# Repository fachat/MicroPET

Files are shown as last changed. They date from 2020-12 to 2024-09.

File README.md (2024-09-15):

# uPET R2

# NOTE: the newer version is in the [cbm_micropet](https://github.com/fachat/cbm_micropet) repository!

This is a re-incarnation of the Commodore PET computer(s) from the later 1970s.

It is build on a Eurocard board and has only parts that can still be obtained new in 2021.
The current version is 2.0B.

Picture of a MicroPET

Here is the [Overview video](https://youtu.be/COlfqcaY7rI)

Some more videos on the build process can be found here [YT 8-bit times](https://youtube.com/playlist?list=PLi1dzy7kw1iybjcUccgjCV4fhNH4IPWSx)

## Features

The board is built with a number of features:

- Commodore 3032 / 4032 / 8032 / 8296 with options menu to select at boot
  - Boot-menu to select different PET versions to run (BASIC 1, 2, 4)
  - 40 col character display
  - 80 col character display
  - 8296 memory map emulation
  - IEEE488 interface (card edge and 24pin flat ribbon cable)
  - Tape connector (card edge)
  - PET graphics keyboard, or alternatively a C64 keyboard
- Improved system design:
  - 512k video RAM, plus 512k fast RAM, accessible using banks on the W65816 CPU
  - boot from an SPI Flash ROM
  - up to 12.5 MHz mode (via configuration register)
  - VGA b/w video output
  - Write protection for the PET ROMs once copied to RAM
  - lower 32k RAM mappable from all of the 512k fast RAM
- Improved Video output:
  - Hires graphics mode (using a configuration register)
  - modifyable character set
  - 40/80 column display switchable
  - 25/50 rows display switch
  - multiple video pages mappable to $8000 video mem address

## Overview

The system architecture is actually rather simple, as you can see in the following graphics.

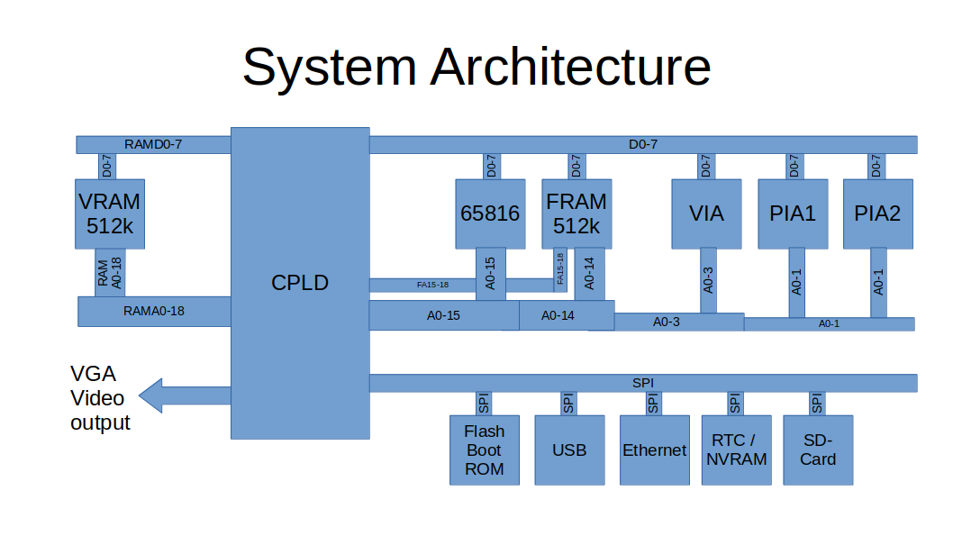
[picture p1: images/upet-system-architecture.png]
MicroPET System Architecture


The main functionality is "hidden" inside the CPLD. It does:

1. clock generation and management
2. memory mapping
3. video generation.
4. SPI interface and boot

On the CPU side of the CPLD it is actually a rather almost normal 65816 computer, 
with the exception that the bank register (that catches and stores the address lines 
A16-23 from the CPU's data bus) is in the CPLD, and that there is no ROM. The ROM has been
replaced with some code in the CPLD that copies the initial program to the CPU accessible
RAM, taking it from the Flash Boot ROM via SPI. This actually simplifies the design,
as 

1. parallel ROMs are getting harder to come by and
2. they are typically not as fast as is needed, and
3. with the SPI boot they don't occupy valuable CPU address space.

The video generation is done using time-sharing access to the video RAM.
The VGA output is 640x480 at 60Hz. So there is a 40ns slot per pixel on the screen, 
with a pixel clock of 25MHz.

The system runs at 12.5MHz, so a byte of pixel output (i.e. eight pixels) has four
memory accesses to VRAM. Two of them are reserved for video access, one for fetching the
character data (e.g. at $08xxx in the PET), and the second one to fetch the "character ROM"
data, i.e. the pixel data for a character. This is also stored in VRAM, and is being loaded
there from the Flash Boot ROM by the initial boot loader.

The CPLD reads the character data, stores it to fetch the character pixel data, and streams
that out using its internal video shift register.

For more detailled descriptions of the features and how to use them, pls see the subdirectory,
as described in the next section.

## Building

Here are four subdirectories:

- [Board](Board/) that contains the board schematics and layout
- [CPLD](CPLD/) contains the VHDL code to program the CPLD logic chip used, and describes the configuration options - including the [SPI](CPLD/SPI.md) usage
- [ROM](ROM/) ROM contents to boot
- [Case](Case/) 3-D printed supports and keyboards to mount board in a C64c case

### Board

To build the board, you have to find a provider that builds PCBs from Eagle .brd files.
Currently no gerbers are provided.

### CPLD

The CPLD is a Xilinx xc95288xl programmable logic chip. It runs on 3.3V, but is 5V tolerant,
so can be directly connected to 5V TTL chips. I programmed it in VHDL.

Unfortunately the W65xx parts are "only" CMOS, and not TTL input chips - but 3.3V is still above
the VCC/2 for the 5V chips. Only Phi2 needs improvements on the signal quality using a pull-up resistor
and specific VHDL programming.

### ROM

The ROM image can be built using gcc, xa65, and make. Use your favourite EPROM programmer to burn it into the SPI Flash chip.

The ROM contains images of all required ROM images for BASIC 1, 2, and 4, and corresponding editor ROMs, including
some that have been extended with wedges.

The updated editor ROMs are from [Steve's Editor ROM project](http://www.6502.org/users/sjgray/projects/editrom/index.html) and can handle C64 keyboards, has a DOS wedge included, and resets into the Micro-PET boot menu.
For more details see the [ROM description](ROM/README.md)

## Future Plans

These are future expansions I want to look into. Not all may be possible to implement.

- n/a

## Gallery

Picture of a MicroPET

Note: the published schematics and board has the extra wires fixed/included.

MicroPET with self-printed key caps

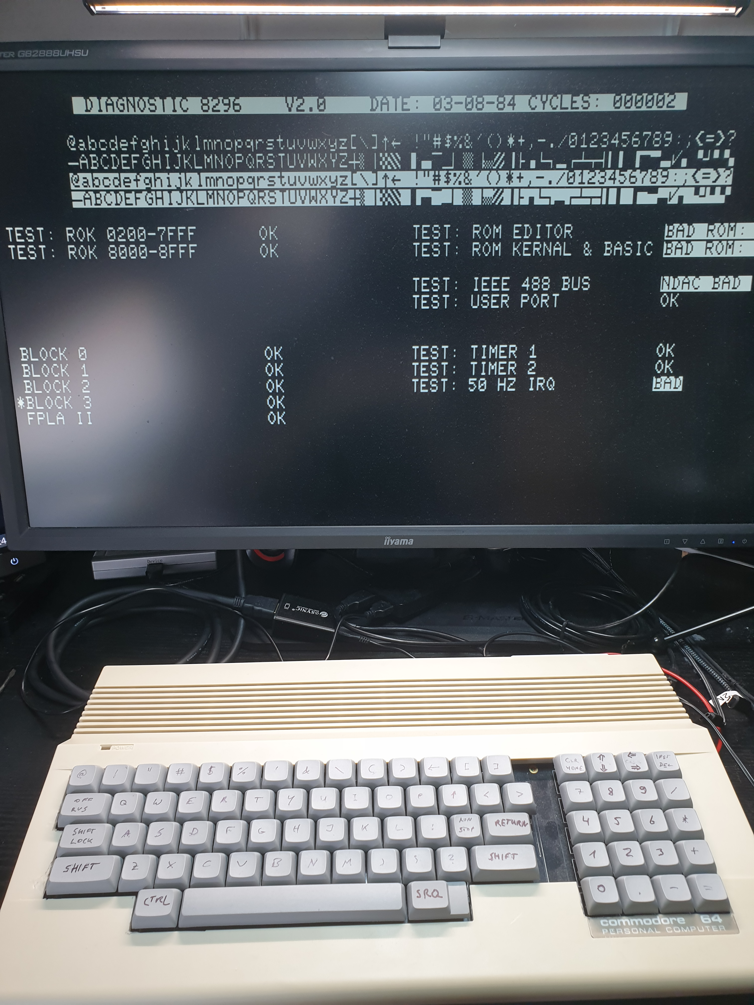
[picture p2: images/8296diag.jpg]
MicroPET running the 8296 burnin


MicroPET before adjusting a C64 case

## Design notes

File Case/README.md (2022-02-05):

# Installing the Micro-PET into a C64c case

I installed the Micro-PET into a C64c case, i.e. the flat one. The reason to select this type of case
is that there are new cases available since the original casts have been recovered.

## Board mounts

The board is screwed onto a support that is itself screwed to the bottom of the case.
Only one screw is used to directly screw the board to the case, the other screws fix the board to the support.

The back cover covers the case holes for the old expansion board hole that is not needed anymore.
It can also be used as template where to cut holes into the C64c case for the IEEE488, VGA, Ethernet and USB connectors.

[board support](board/MicroPET board mounts with batt holder.stl)
[back cover](board/Final MicroPET Back Cover.stl)

## Keyboard

### Options

There are three keyboard options available:

1. The open source [keyboard by Steve J. Gray](http://www.6502.org/users/sjgray/projects/mxkeyboards/index.html), using the "N-V1-R2" boards there.
2. The Petskey v1.0 keyboard from [texELEC](https://texelec.com/product/petskey/)
3. An original C64 keyboard.

The first two options are replacements for an N-type PET keyboard, the third options is a C64 keyboard.
The boot menu will detect which keyboard is used by noting which key is pressed to select the PET model, 
and will automatically load the right editor ROM (except for BASIC2 that only works with the N keyboard).

Note that options 1. and 2. will need MX key switches, preferrably of the 5 pin type that better locks in
and alignes in the right direction. Also, for thos switches you need to have appropriate key caps (see below).

### Supports

For each of the options there are different keyboard supports. You need the common
[keyboard support plate](kbd_support/C64c%20keyboard%20support%20plate.stl) and the C64 keyboard supports, i.e. two of [supports for C64 keyboards](kbd_support/C64%20keyboard%20support.stl).
Using these parts you can use a C64 keyboard. 

If you want to use a PET keyboard, you have two options:
1. two [supports for SJG keyboards](kbd_support/sjg%20keybd%20full%20support%20plate.stl) or
2. two [supports for petskey keyboards](kbd_support/petskey%20full%20support%20plate.stl), or

Two of each of those make up a keyboard base plate, where you only need to clip in the PCB for the keyboard
with the mounted key switches. Then they have about the same dimensions as a C64 keyboard, and you can use
them on top of the C64 keyboard support stands.

### Standard Keycaps

As, for the self-built keyboards from option 1 or 2 some standard MX switches are used, standard 
key caps can be used as well. There is one caveat, however.

Newer key caps typically have a different inclination for each row of keys, that is the angle of the top key surface against the horizontal
is different for each row. This is to facilitate easier typing. In fact even the C64 keyboard has this.
The old PET keyboards, however, have the same angle - which is not zero! - for all rows. This makes it easier to use the same cap (in terms of physical dimensions)
on all rows, and just print on a different character for each key. Read more on those [key profiles](https://switchandclick.com/sa-vs-dsa-vs-oem-vs-cherry-vs-xda-keycap-profiles/).

I used two type of standard key caps:

1. [XDA profile, unmarked](https://www.amazon.de/gp/product/B06XSHK528/): this set of key caps does not have a print on it, and all keys have the same angle - zero. So it is 
possible to use any of the key caps in any row. Which is important, as you need a specific number of keys for each key width.
Also, this set has space bars in different lengths, and there is one that fits the 6.25 character wide space bar for the petskey and sjg keyboards.
For the markings I just used a pen...

2. This one [Glorious PC Gaming Race ABS Doubleshot black, ANSI layout GAKC-045](https://www.caseking.de/glorious-pc-gaming-race-abs-doubleshot-schwarz-ansi-us-layout-gakc-045.html) I actually bought more or less 
by accident. I only noticed that it has different angles per row when I tried it out. However, with the amount of caps I was able to only
use a wrong angle on Shift Lock, left Shift, Return and "4" - but it's barely noticable.
For the markings I used template from Steve's page, printed it on sticky paper, cut it out and glued it on the keys where the original did not fit.

### Printed Keycaps

As a third option I used 3-D printed key caps that I designed myself. 

The keycaps are made of three parts each:
1) a key form created by a parametric generator,
2) the top character print, extruded from the key form,
3) the front character (mostly the shifted character), extruded from the key form.

I created all parts, and integrated them in the [Tinkercad](https://tinkercad.com) web tool.

The key form is created using OpenSCAD by a [parametric generator](https://www.thingiverse.com/thing:2783650) (by Thingieverse user rsheldiii, published under the [CC BY-SA 3.0](https://creativecommons.org/licenses/by-sa/3.0/) license). Here is the [parameter file](keycaps/key_cbm3_customizer.scad). Only the key width needs to be adapted, and the inversion of the top for the space key.

Most of the top character prints are made from a [Microgramm font](https://www.wfonts.com/font/microgramma), converted to SVG using the [Font Squirrel](https://www.fontsquirrel.com/tools/webfont-generator) web page.

Some top characters, and especially the top words ("SHIFT", "RUN STOP" etc) are taken from [Steve's github page](https://github.com/sjgray/CBM-MX-Keyboards/tree/master/stickers). As SVG exported from inkscape did not work when imported
into tinkercad, I had to make screenshots from each character, and convert these screenshots into SVGs using this [online converter](https://image.online-convert.com/convert-to-svg). 

The front characters are all from an [SVG file from wikipedia](https://en.wikipedia.org/wiki/Commodore_PET#/media/File:PET_Keyboard_improved.svg), from which I also took screenshots and converted to SVG as above.

You can find the STL files [here](keycaps/), in four parts due to its size.
Please note that it took me about 100+ hours just to print the full set of keys on my Snapmaker printer in high quality.
After printing you have to remove the supports that anchor the stem to the outside of the keycaps so it does
not break away when printing.

## Designs

Here are the links to the Tinkercad designs I created:

1. [Keycaps]( https://www.tinkercad.com/things/dNZ8wI2zuYY )
2. [base plate for keyboard support]( https://www.tinkercad.com/things/4DlYD3iQAby )
3. [keyboard plates for Steve Gray's keyboard (needed 2x, on top of C64 keyboard supports)](  https://www.tinkercad.com/things/a3phGKtNsUp  )
4. [keyboard plates for petskey keyboard (needed 2x, on top of C64 keyboard supports)](  https://www.tinkercad.com/things/5lenSoehSRu  )
5. [keyboard supports for C64 keyboard]( https://www.tinkercad.com/things/6t9EtqgGbSE )
6. [Board mount]( https://www.tinkercad.com/things/aFCF30m60Vp )
7. [Back cover]( https://www.tinkercad.com/things/5eZ8UNyYb2q )

## License

The material here is published under the Creative Commons Attribution-ShareAlike 3.0 [CC BY-SA 3.0](https://creativecommons.org/licenses/by-sa/3.0/) license.

## Gallery

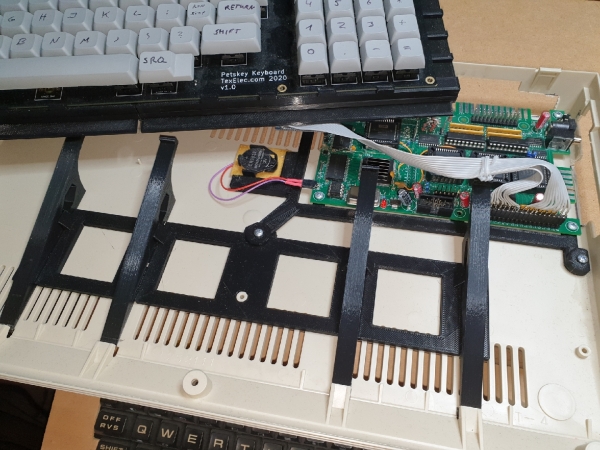
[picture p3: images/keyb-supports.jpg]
Keyboard supports


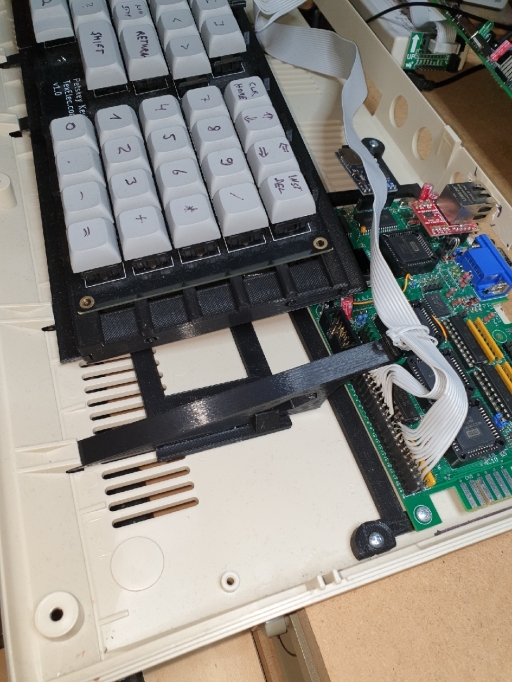
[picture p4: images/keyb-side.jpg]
Keyboard side view with plate


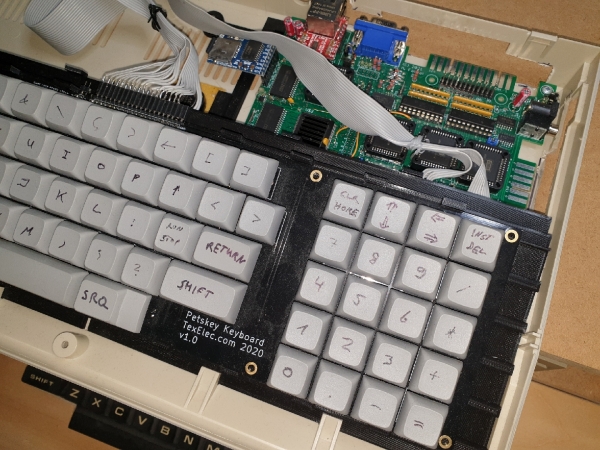
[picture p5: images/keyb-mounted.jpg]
Keyboard mounted on plate


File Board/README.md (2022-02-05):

# Board V2.1A

The board is a two-layer Eurocard, i.e. 160mm x 100mm.

## Schematics & Layout

The schematics and layout have been created with Cadsoft Eagle.
So, here you can find the 

- [micropet_v2.sch](micropet_v2.sch) and
- [micropet_v2.brd](micropet_v2.brd) files

But, you can still have a look at the schematics and layout using the
PNG images created

- [micropet_v2-sch-1.png](micropet_v2-sch-1.png) Part 1 - PETIO
- [micropet_v2-sch-2.png](micropet_v2-sch-2.png) Part 2 - CPLD, CPU, RAM
- [micropet_v2-sch-3.png](micropet_v2-sch-3.png) Part 3 - Power
- [micropet_v2-sch-4.png](micropet_v2-sch-4.png) Part 4 - Video and Audio output
- [micropet_v2-sch-5.png](micropet_v2-sch-5.png) Part 5 - SPI devices (Eth, USB, RTCC, ...)

## Bill of Material

The main chips are:

- 1x W65816S CPU
- 2x W65C21N PIA
- 1x W65C22N VIA

- 1x xc95288xl CPLD
- 2x 8x512k parallel SRAM with 25ns access time
- 2x 74LS641-1
- 1x 74LS145 4-to-10 BCD O.C. driver (keyboard)
- 1x 74LS07
- 1x DS1813 RESET controller

- 50 MHZ crystal oscillator

- Voltage regulator

- x 0.1uF bypass caps

- 5.1kOhm / 2.4kOhm pairs of resistor arrays for IEEE488
- 10kOhm pullup
- 1x 1kOhm pullup
- 1x 8x10kOhm resistor array (keyboard pull up)

- div. resistors/caps to generate 3.3V output

More details can be found in the [Eagle parts list](micropet_v2.parts).

## Changelog

### V2.1A

In this version I incorporated the fixes I had to apply to the first prototype board. Also, I changed the IEEE488 circuit such that it can now really work as a disk drive for another PET. This brings it in line with the CSA PETIO 1.2A/1.3A boards that have this functionaly fixed.

## Erratum

This section describes fixes from my 2.0A prototype board, and these are the cuts/additional wires you see on the pictures, where I fixed my 2.0A boards.

### 2.0C

- I pulled up /IRQ to 5V, but that was potentially backfeeding to the 3.3V SPI devices. A pull-up to 3.3V still worked just fine without problems

### 2.0B

- In 2.0A I planned to use the 74245 to drive the system's Phi2 clocks (CPU & I/O), and to level-shift it. But it turned out that this was not stable, so I reverted to the pull-up resistor method again
- I was missing a cross-sheet connection for the I/O Phi2 clock
- Also I was missing the SPI select line for the RTCC

- 
-

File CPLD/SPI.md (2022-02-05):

# SPI interface

## Overview

The SPI interface is as simple as I could make it, to save resources in the CPLD.

Nevertheless it has a transmit data register where data can be loaded to transmit, even if the
previous transmit is already in progress.
Also, there are two registers to read the data - one that just returns the current shift register value,
and another that automatically triggers reading a new byte from SPI.
These two features are implemented to increase throughput.

The CPHA and CPOL bits in the control register can be used to select the required SPI mode.

## Register Set

The SPI interface has four addresses, of which 3 are currently used:

- $e808: control register (read/write)
  - Bit 0-2: SPI device selection (write only)
  - Bit 3: - unused, must be 0
  - Bit 4: CPHA (write only)
  - Bit 5: CPOL (write only)
  - Bit 6: 1: tx data register is occupied; 0: tx data register is free, you can reload it (read only)
  - Bit 7: 1: shift register is in use (read only)

- $e809: data register (read/write)
  - Read: Bit 0-7: read the current state of the shift register, and trigger reading a new byte from SPI
  - Write: Bit 0-7: write to the transmit data register, and start shifting it out (waiting for a previous byte to finish if needed)

- $e80a: data register (peek)
  - Read: Bit 0-7: read the current state of the shift register

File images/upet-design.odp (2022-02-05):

## System Architecture

A0-14

A0-3

A0-1

A0-1

FA15-18

A0-15

D0-7

D0-7

D0-7

D0-7

D0-7

RAM
A0-18

D0-7

SPI

SPI

SPI

SPI

SPI

D0-7

RAMD0-7

CPLD

VRAM

512k

65816

FRAM

512k

VIA

PIA1

PIA2

FA15-18

A0-15

RAMA0-18

A0-14

A0-3

A0-1

VGA

Video

output

SPI

Flash
Boot
ROM

USB

Ethernet

RTC /
NVRAM

SD-
Card

## Memory Map (boot)

ipl

ipl

CPU address space (lower 1M)

64k
bank0

Banks 0 … 7

Banks 8 … 15

64k
bank0

64k 8296

Ext. bank

Banks 2 … 7

64k video
bank

Banks 9 … 15

512k FRAM

Physical address space

The CPLD can only write (the IPL code from Flash) to VRAM, so the initial

Mapping maps VRAM to banks 0-7 of the CPU

512k VRAM

## Memory Map

CPU address space (lower 1M)

0-32k

32-
64k

Banks 1 … 15

Any of 16

32k blocks

In FRAM

4k
V

Bank 0, or

8296 mem expansion

In bank 1

Any of four 2k positions in video bank

8k
Chr

rom

8k
Chr

64k
bank0

64k 8296

Ext. bank

Banks 2 … 7

64k video
bank

Banks 9 … 15

512k FRAM

Physical address space

512k VRAM

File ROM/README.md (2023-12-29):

# ROM contents

This folder contains files and code to build a ROM image that can be burned into the 512k ROM on the board, so that it actually boots.

- iplldr.a65: initial program loader, boots the machine by:
-- copying over character ROM image from start of ROM ($0f0000) to start of bank 7 (in RAM)
-- letting the user select which machine to boot (BASIC 2, BASIC 4/40 columns, BASIC 4/80 columns)
-- copying over selected PET ROM image to bank 0 ($a000-$ffff) ...
-- and executes a JMP through the RESET vector

For this work the ROM needs to contain:
- boot code
- character ROM
- system ROMs

## SPI FLash Memory Map

The IPL triggered by the CPLD loads the first 256 byte from the SPI flash. Following that is the
rest of the boot code as loaded by the initial IPL loader.
Then follow the various ROM images.

	Boot Image
        
        +----+ $1ffff
        |    |         SD-Card DOS code
        |    |         (16k)
        |    |
        +----+ $1c000
        |    |         USB driver code
        |    |         (8k)
        +----+ $1a000
        |    |         BASIC 1 alternate charrom 
        |    |         (as 16 byte/char)
        +----+ $18000
        |    |         8x BASIC 4 EDITOR
         ...           ROM images ($e000-$efff)
        |    |         Extended/orig, 40/80 columns, N-type/C64 kbd
        |    |
        +----+ $10000
        |    |         BASIC 4 Kernal ROM image
        +----+ $0F000
        |    |         BASIC 4 
        |    |         ROM image ($b000-$dfff)
        |    |         
        +----+ $0c000
        |    |         BASIC 2 
        |    |         ROM image ($c000-$ffff)
        |    |  
        |    |       
        +----+ $08000
        |    |         BASIC 1 
        |    |         ROM image ($c000-$ffff)
        |    |
        |    |
        +----+ $04000
        |    |         8k PET charrom
        |    |         (16 byte per character)
        +----+ $02000
        |    |         4k @MON in the PET4 variant (without editor extension)
        +----+ $01000
        |    |         Boot loader, first 256 byte IPL's by CPLD
        +----+ $00000

## Build

To build the ROM, just run "make".
This build process for bootimg downloads the necessary ROM images and sub-repos from the internet, builds the boot loader, and combines everything into a single boot image.
Then burn the resulting file "spiimg" into the lowest bank of the SPI Flash ROM (Address 0)

## Files

The following files are test files, or to build the ROMs:

- char8to16.c: converts a character ROM with 8 pixel rows per character to a 16 row per character image
- charPet2Invers.c: a PET charrom is only 2k and lacks inverted characters, as they are generated by hardware. This small program creates, from the 2k PET image, a full 4k image that contains the inverted characeters
- edit....asm: control files for Steve Gray's editor ROM project, to build the custom editor ROMs
-- edit40gx: 40 column for graphics keyboard with wedge and special keys
-- edit80gx: 80 column for graphics keyboard with wedge and special keys
-- edit40gxc: 40 column for C64 keyboard with wedge and special keys
-- edit80gxc: 80 column for C64 keyboard with wedge and special keys
-- edit40gc: 40 column for C64 keyboard (no further extensions) 
-- edit80gc: 80 column for C64 keyboard (no further extensions)

## ROM features

The editor ROMs are non-standard, and feature some extensions.
Note that they are only available for BASIC 4 variants. BASIC 1 and 2 are only just that.

### Extended versus Base ROMs

In the boot menu you can select the various model. By default the 
extended editor ROM is loaded where available (i.e. including wedge and special keys).
If you select the model while pressing the LEFT SHIFT, the unmodified ROM
is loaded. One exception: there is no original 80 column N-type keyboard ROM, so 
a contemporary adaption is used.

The BASIC 1 Kernal has the problem that its IEEE488 routines are broken.
Therefore, by default, a version that is patched to fix this is loaded,
so IEEE488 can be used. Selecting "1" with LEFT-SHIFT pressed installs
the original BASIC 1 ROMs.

Note that pressing the RIGHT SHIFT is not what you want. Doing this on the
N-type keyboard makes the select routing think you are using a C64 keyboard
instead, and the machine becomes unusable.

### Graphics keyboard ROMs

These are derived from the standard PET ROMs, but feature some extensions:

1. Shift + '@': switch between text and graphics display.
1. '@' + Left-Shift + Right-Shift + DEL: reset the PET

### C64 keyboard ROMs

The ...gc ROM files enable the use of a C64 keyboard instead of a PET graphics keyboard. 
The initial boot loader, where the model is selected detects the keyboard used using the numbers
pressed to select the model, and automatically loads the correct ROM.

Note that due to code size restrictions, only the normal and shifted keys are supported. CBM and Control
are currently ignored.

The follwing features are present:

1. Shift + Left-Arrow: switch between text and graphics display.
1. Ctrl + Left-Shift + Right-Shift + DEL: reset the PET

### Extended machine language monitor

In the ROM area at $a000 there is the @MON machine language monitor included (with assembler
and disassembler, and versatile search functions). 

Note that the scrolling editor is (for now) disabled due to incompatibilities with the modified
editor ROMs.

## Runtime Memory Map

When the different ROM versions are used, the memory map is installed as follows:

### BASIC 1 & 2

	Video RAM 
        
        +----+ $0fffff
        |    |
         ...           free
        |    |
        +----+ $089000
        |    |         Video data (mapped to bank 0)
        +----+ $088000
        |    |
         ...           free
        |    |
        +----+ $082000
        |    |         character ROM
        |    |         (two sets, 8k total, as 16 byte/char)
        +----+ $080000

	Fast RAM

        +----+ $07ffff
        |    |  
         ...           free
        |    |
        +----+ $010000
        |    |         BASIC 1/2 Kernal ROM image
        |    |
        +----+ $00F000
        |    |         BASIC 1/2 Editor 
        |    |         with I/O window at $E8xx
        +----+ $00E000
        |    |         BASIC 1/2 
        |    |         ROM image ($c000-$ffff)
         ...          
        |    |
        +----+ $00C000
        |    |
         ...           free
        |    |
        +----+ $009000
        |    |         Video window (mapped from Video RAM
        +----+ $008000
        |    |         32k BASIC RAM
         ...          
        |    |        
        +----+ $000400
        |    |         system variables
        +----+ $000200
        |    |         CPU stack
        +----+ $000100
        |    |         zeropage variables
        +----+ $000000

### BASIC 4

With BASIC 4 there are multiple options that need to be considered:

1. CBM 8x96 memory map emulation
2. USB and SD-Card support

	Video RAM 
        
        +----+ $0fffff
        |    |
         ...           free
        |    |
        +----+ $089000
        |    |         Video data (mapped to bank 0)
        +----+ $088000
        |    |
         ...           free
        |    |
        +----+ $082000
        |    |         character ROM
        |    |         (two sets, 8k total, as 16 byte/char)
        +----+ $080000

	Fast RAM

        +----+ $07ffff
        |    |  
        +----+ $078000
        |    |         USB- and SD-Card support bank, mapped 
        |    |         into lower half of bank 0 when active
        +----+ $070000
        |    |  
         ...           free
        |    |
        +----+ $020000
        |    |         8x96 extension memory, can be mapped in two chunks
        |    |         with 16k each into upper half of bank 0 using $fff0
        +----+ $010000                                   +----+   +----+  $00FFFF
        |    |         BASIC 4 Kernal ROM image          |    |   |    |
        |    |                                           |    |   |    |  Two sets of 16k pages
        +----+ $00F000                                   |    |   |    |  mapped from bank 1
        |    |         BASIC 4 Editor - multiple options |    |   |    |
        |    |         with I/O window at $E8xx          |    |   |    |
        +----+ $00E000                                   |    |   |    |
        |    |         BASIC 4                           |====|   |====|  optional peek-through to I/O
        |    |         ROM image ($b000-$ffff)           |    |   |    |
         ...                                             +----+   +----+  $00C000
        |    |                                           |    |   |    |
        +----+ $00B000                                   |    |   |    |  Two sets of 16k pages
        |    |         Extended @ASS monitor             |    |   |    |  mapped from bank 1
        |    |         (start with SYS49060)             |    |   |    |
        +----+ $00A000                                   |    |   |    |
        |    |         free                              |    |   |    |
        +----+ $009000                                   |----|   |----|
        |    |         Video window (mapped from VRAM)   |    |   |    |  optional peek-through to video
        +----+ $008000                                   +----+   +----+  $008000
        |    |         32k BASIC RAM                     |    |
         ...                                             |    |
        |    |                                           |    |
        +----+ $000400                                   |    |  Any of the 16 32k pages
        |    |         system variables                   ...    in bank 0, mapped
        +----+ $000200                                   |    |  using Memory bank register $e802
        |    |         CPU stack                         |    |
        +----+ $000100                                   |    |
        |    |         zeropage variables                |    |
        +----+ $000000                                   +----+   $000000

### USB/SD-Card map

The USB driver and the SD-Card DOS code are run mapping their 32k area into the
lower half of bank 0. There they can use their own zeropage or even stack if needed.

The boot code copies the files from the SPI image there and, if needed, patches
the BASIC4/KERNAL4 in place to link the USB/SD-Card support in.

The currently used memory is as follows:

#### USB driver

Zeropage reserved: $02-$10
Code/Data reserved: $1000-$3000

These values come from the reloc65 (-v) output in the usb65/platform/upet build code when creating the 
ROM image.

text segment @ $1000 - $24a3,  5283 ($14a3) bytes
data segment @ $24a3 - $28b2,  1039 ($040f) bytes
bss  segment @ $28b2 - $2a93,   481 ($01e1) bytes
zero segment @ $0002 - $0011,    15 ($000f) bytes

#### SD-Card / DOS

Zeropage reserved: $10-$20
Code/Data reserved: $3000-$8000

These values are configured in the ca65/ld65 linker configuration:

ZPDOS:    start = $0010, size = $000B;
DOS:      start = $4000, size = $4000, fill=yes, fillval=$AA;
DOSDAT:   start = $3000, size = $1000;

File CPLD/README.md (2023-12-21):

# CPLD code for the MicroPET 1.0

The CPLD is a Xilinx xc95288xl chip, a 5V tolerable CPLD running with 3.3V supply voltage.
I programmed it in VHDL.

## Overview

This is an overview on the register set:

- $e800 (59392)  [Video control](#e800-59392-video-control)
- $e801 (59393)  [Memory map control](#e801-59393-memory-map-control)
- $e802 (59394)  [Low32k bank / video window map](#e802-59394-low32k-bank)
- $e803 (59395)  [Speed control](#e803-59395-speed-control)
- $e805 (59397)  [Video window map](#e805-59397-video-window)

- $fff0 (65520)  [8296 memory control (8296 memory map only)](#8296-control-port)

- $e880/e881 (59520/59521) [CRTC emulation](#crtc-emulation)
  - register 9: pixel rows per char - 1
  - register 12: start of video memory high

## Control Ports

### Micro-PET

There are four control ports at $e800 - $e803. They are currently only writable.

#### $e800 (59392) Video Control

- Bit 0: 0= character display, 1= hires display
- Bit 1: 0= 40 column display, 1= 80 column display
- Bit 2: 0= screen character memory in bank 0, 1= character memory only in video bank (see memory map)
- Bit 3: 0= double pixel rows, 1= single pixel rows (also 400 px vertical hires)
- Bit 4: 0= interlace mode (only every second rasterline), 1= duplicate rasterlines
- Bit 5: unused - must be 0
- Bit 6: 0= when switching char height, move vsync to keep screen centered. 1= prevent that
- Bit 7: 0= video enabled; 1= video disabled

##### Screen mirror in bank 0

The CRTC reads its video data from the video bank in VRAM.
This is not mapped to bank 0 in the CPU address space, as it is "slow" memory, because
the available memory bandwidth is shared with the video access.

To allow the PET code to directly write to $8xxx for character video memory, Bit 2 maps
the $8xxx window in CPU bank 0 to the VRAM video bank.

Note that with the register $e802, the position of the video window in the video bank
can be changed (while it stays at $8xxx in the CPU memory bank 0). This allows 
for easy switching between multiple screens beyond the 4k limit of the PET video memory
window at $8xxx.

##### Interlace and 50 row mode

In normal mode (after reset), the VGA video circuit runs in interlace mode,
i.e. only every second raster line is displayed with video data.
Writing a "1" into Video Control register bit 4, interlace is switched off, and every
single line is displayed with video data. 

As long as bit 3 is 0, every rasterline is 
displayed twice, to get to the same height as in interlace mode.
If bit 3 is 1, then every rasterline is a new rasterline.
So, setting bit 3=1 and bit 4=1 gives double the number of character rows
(or raster rows in bitmap mode). I.e. with this you can enable 50 character row
screens.

##### Moving Sync

The character height can be switched between 8 pixel rows and 9 pixel rows (using 
R9 of the emulated CRTC, see below). 
This gives a displayed height of the screen of either 400 or 450 (each rasterline is
displayed twice, see previous section). 

For the video code, the screen starts with the first displayed rasterline. The sync position
is fixed to that position, i.e. it has a fixed rasterline where the vertical sync is triggered.
The value is selected such, that the displayed data is about centered on the screen.

Now, if the character height is changed, the height of the displayed data is changed, and to 
keep the this area vertically centered, the position of the vertical sync in relation to the 
first rasterline is moved. 

However, as there just isn't enough space in the CPLD, when this happens, the distance between
two vertical sync signals changes for one displayed frame. Some monitors may have difficulties
with this, trying to find a new video mode and switching the display off during that search 
attempt. 

In normal operation that does not matter, as this mode should be set once and then left as it is.
But for programs that may switch character height more often, this may be irritating. So,
with bit 6 you can disable moving the vertical sync. The displayed data will stay relatively
high on the screen, and just the lower border moves up and down when the character height is
changed. Then the monitors don't recognize a potential mode change, and thus don't blank
the screen. It just isn't properly centered anymore.

#### $e801 (59393) Memory Map Control

- Bit 0: 0= allow cross-bank access in emulation mode, 1= lock CPU into bank 0 in emulation mode
- Bit 1: 0= normal mode, 1= initial boot mode, swap FRAM and VRAM (see above)
- Bit 2: unused, must be 0
- Bit 3: 0= 8296 mode is disabled / locked ($fff0 disabled); 1= 8296 control port $fff0 enabled
- Bit 4: 0= $009xxx is writable, 1= write protected
- Bit 5: 0= $00Axxx is writable, 1= write protected
- Bit 6: 0= $00Bxxx is writable, 1= write protected
- Bit 7: 0= $00C000-$00FFFF is writable, 1=write protected (except I/O window at $e8xx)

#### $e802 (59394) Bank Control

- Bit 0-3: number of 32k bank in 512k RAM, for the lowest 32k of system
- Bit 4-7: unused, must be 0

Map the lowest 32k in bank 0 to any of 16 32k blocks in the 512k Fast RAM.

#### $e803 (59395) Speed Control

- Bit 0/1: speed mode
  - 00 = 1 MHz
  - 01 = 2 MHz
  - 10 = 4 MHz
  - 11 = 12.5 MHz with wait states for video access to VRAM
- Bit 2-7: unused, must be 0

#### $e805 (59397) Video window

- Bit 0: when set, swap the 2 2k areas at $8000 and $8800
- Bit 1-2: number of 2k character video memory block the $8xxx window points to; possible 
addresses in VRAM bank 0 (CPU bank 8) are $8xxx, $9xxx, $axxx, $bxxx
- Bit 3-7: unused, must be 0

If you use 2k of 4k screens, you can use 
Bits 0-2 as address bits for where the video memory at $8000-$87ff is mapped in
the actual video RAM. The difference is in the mapping of the second 2k at $8800-$8fff.
This second half is not just 2k after the character video memory, but always in the same 
4k block in video memory as the actual character video memory at $8000. Technically,
bit 0 just inverts address bit A11.

So, for example value of "001" maps:

- $8000-$87ff to $8800-$8fff
- $8800-$8fff to $8000-$87ff

Where "010" maps:

- $8000-$87ff to $9000-$97ff
- $8800-$8fff to $9800-$9fff

### 8296 control port

This write only control port at $fff0 (65520) enables the RAM mapping in the upper 32k of bank 0, as implemented
in the 8296 machine. The address of this port is $FFF0.
To enable it, bit 3 in the Memory Map Control register must be set.

- Bit 0: 0= write enable in $8000-$bfff, 1= write protected
- Bit 1: 0= write enable in $c000-$ffff, 1= write protected
- Bit 2: select one of two block to map for $8000-$bfff (starts either $010000 or $018000)
- Bit 3: select one of two block to map for $c000-$ffff (starts either $014000 or $01c000)
- Bit 4: - unused, must be 0 -
- Bit 5: 0= RAM in $8xxx, 1= screen peek-through the mapped RAM
- Bit 6: 0= RAM in $e8xx, 1= I/O peek-through the mapped RAM
- Bit 7: 0= RAM mapping disabled, 1=enabled

## CRTC emulation

The Video code (partially) emulates only a subset of the CRTC registers:

- Register 9: number of pixel rows per character -1
- Register 12: start of video memory high

All the other registers are not emulated, so any program or demo that
uses them will fail.

As usual with the CRTC, you have to write the register number to $e880 (59520),
the write the value to write to the register to $e881 (59521).

### Video memory mapping

The video memory is defined as follows:

#### Character mode

In character mode (see control port below) two memory areas are used:

1. Character memory and
2. Character pixel data (usually "character ROM")

Register 12 is used as follows:

- Bit 0: - unused - must be 0
- Bit 1: - unused - must be 0
- Bit 2: A10 of start of character memory
- Bit 3: A11 of start of character memory 
- Bit 4: A12 of start of character memory
- Bit 5: A13 of start of character memory
- Bit 6: A13 of character pixel data (charrom)
- Bit 7: A14 of character pixel data (charrom)

As you can see, the character memory can be mapped in 1024 byte pages.
14/15 of character memory address are set to %10, so character memory
starts at $8000 in the video bank, and reaches up to $bfff

For 40 column mode this means 16 screen pages, or 8 screen pages in 80 column mode.
Character memory is mapped to bank 0 at boot, but can be unmapped and only be available in bank 8 (VRAM) using the control port

The character set is 8k in size: two character sets of 4k each, switchable with the 
VIA I/O pin given to the CRTC as in the PET. Register 12 can be used to select
one of 4 such 8k sets. Note that each character occupies 16 bytes (not 8 as in the typical
Commodore character set), so the 9th rasterline for a character may be used.
Character set data is mapped to the lower half of bank 8 (VRAM bank 0, i.e. A15=0).

#### Hires mode

Hires mode is available in 40 as well as 80 "column" mode, i.e. either 320x200 or 640x200 pixels.

Register 12 here is used as follows:

- Bit 0: - unused - must be 0
- Bit 1: - unused - must be 0
- Bit 2: A10 of start of hires data
- Bit 3: A11 of start of hires data
- Bit 4: A12 of start of hires data
- Bit 5: A13 of start of hires data
- Bit 6: A14 of start of hires data
- Bit 7: A15 of start of hires data

## Memory Map

The memory map looks as follows. There are 512k "Fast" RAM
that make up banks 0-7, and 512k "Video" RAM that make up banks 8-15.

### Standard Map

This map describes the standard memory map, that is enabled after the
SPI boot code has executed and initiated the memory map.

RAM bank 8 is the "video" bank in that hires graphics and character ROMs 
are mapped here. The character data is be mapped there as well but can be
mapped for writing to bank 0 using bit 2
of the control register (see below).

RAM bank 1 is the one used for the 8296 RAM extension (that is mapped into the
upper 32k of bank 0 when the 8296 control register at $fff0 is set.

    Video   +----+ $100000
    RAM     |    |         VRAM 
            |    |         bank 15 
            +----+ $0f0000
            |    |
             ...
            |    |
            +----+ $090000
            |    |         VRAM
            |    |	   bank 8 (video)
            +----+ $080000
    Fast    |    |         FRAM
    RAM     |    |         bank 7
            +----+ $070000
            |    |
             ...
            |    |
            +----+ $020000
            |    |         FRAM
            |    |         bank 1 (8296 mapped memory)
            +----+ $010000
            |    |         FRAM (PET ROM / I/O / 4k Video mapped from VRAM) $8000-$ffff
            |    |         FRAM (lower 32k)
            +----+ $000000

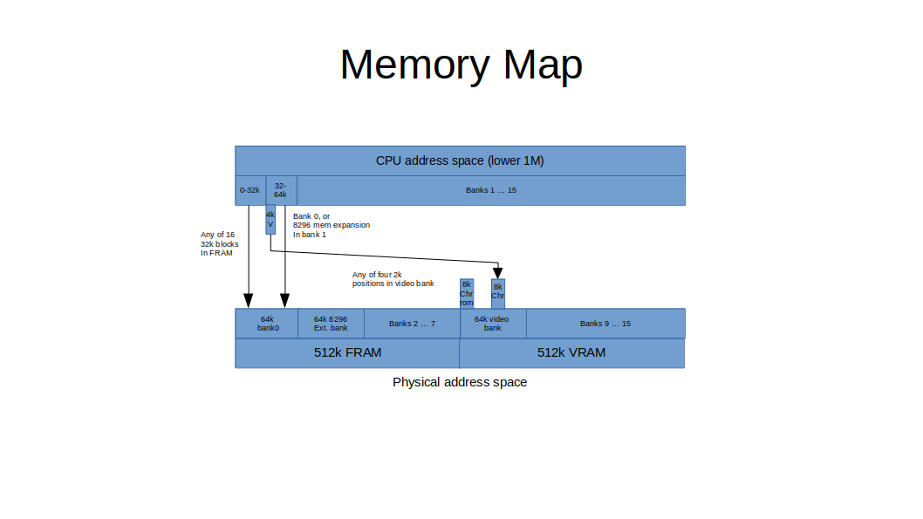
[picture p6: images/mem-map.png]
MicroPET Typical memory map


### Init Map

When the CPU boots, it tries to do so from bank 0. Here we have RAM, so we have to provide some 
initial mapping.

The problem here is that the CPU boots from bank 0, but the CPLD can only
write to Video RAM. So, the boot code from the SPI Flash can only be written
into Video RAM to boot the CPU. Therefore, a bit in the control register
switches the two RAM areas. On hardware reset the Video RAM is mapped to 
banks 0-7 and Fast RAM to banks 8-15. 

The first thing the boot code does is to copy itself to Fast RAM, and
switch over the two RAM chips.

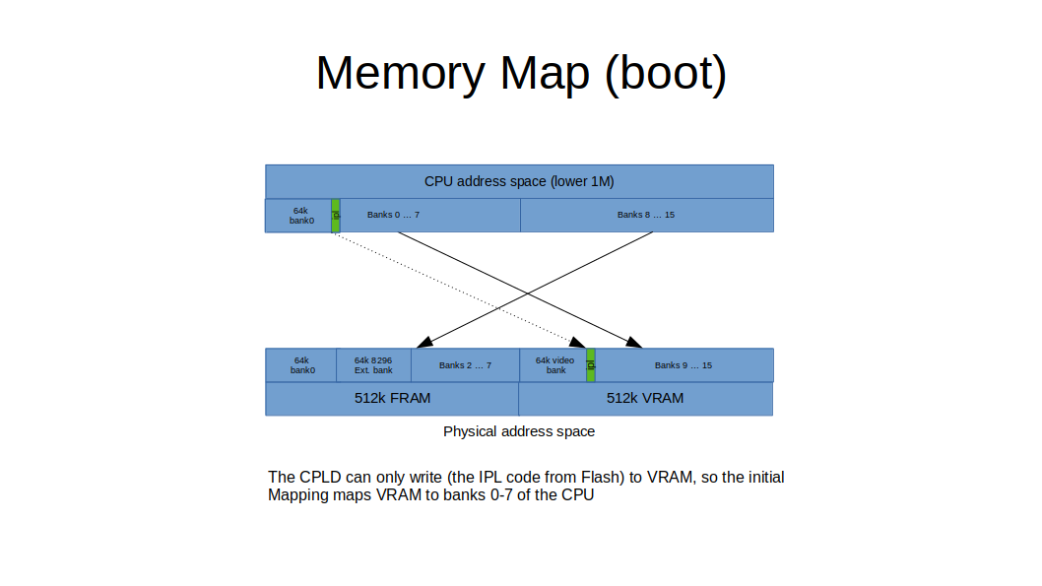
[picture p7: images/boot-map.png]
MicroPET Boot memory map


### Video Map

#### Character memory

The following diagram describes the way that the character video memory is addressed.

             Video    +----+ $090000
             BANK     |    |        
                      |    |	 
                      |    |	 
                      +----+ $08e000	 
     CPU              |    |	 
     Bank 0           |    |
       |              |    |	 
       |              +----+ $08c000
       |      /---->  |    |	BCtrl 4/5 -> 11 / CRTC12 -> $30
     $9000    |       +----+ $08b000
       | -----+---->  |    |	BCtrl 4/5 -> 10 / CRTC12 -> $20
     $8000    |       +----+ $08a000
       |      |\--->  |    |	BCtrl 4/5 -> 01 / CRTC12 -> $10
       |      |       +----+ $089000
       |      \---->  |    |	BCtrl 4/5 -> 00 / CRTC12 -> $00
       |              +----+ $088000
       |              |    |	 
                      |    |	 
                      |    |	 
                      +----+ $088000	 
                      |    |	 
                      |    |	 
                      |    |	 
                      +----+ $086000	 
                      |    |	 
                      |    |	 
                      |    |	 
                      +----+ $084000	 
                      |    |	 
                      |    |	 
                      |    |	 
                      +----+ $082000	 
                      |    |	 
                      |    |	 
                      |    |	 
                      +----+ $080000

Using the Bank control register, the $8xxx window in bank 0 (if enabled via Video control
register), maps to one of four 4k blocks in the video RAM. 
The four blocks start at $088000, $08a000, $08b000, and $08c000 repectively.

At the same time CRTC register 12 can be used to fetch the video data from 
any of the blocks starting at 1k boundaries from $088000 ... $08cc00.

This way one character video block can be mapped to CPU bank 0, while the CRTC
fetches its video output data from another video output block.
This can be used to implement double buffering, or even multiple virtual
"machines" 

#### Character generator memory

The following diagram describes the way that the char generator memory is addressed.
The Character generator memory is the memory that holds the pixel data for each character.
Each character has 16 consecutive bytes, so that the maximum of 9 pixel rows per
character can be handled. As a character has 16 bytes, a character set of 256 characters
has a character generator of 4k.

The Bank Control register allows to select 4 blocks of 8k for the character generator memory,
located at the lower half of the Video Bank 8.
In each 8k, there are two sets of character generators, of 4k each. The one to use is selected by the
VIA CA2 output pin as on the PET.

       Video    +----+ $090000
       BANK     |    |        
                |    |	 
                |    |	 
                +----+ $08e000	 
                |    |	 
                |    |
                |    |	 
                +----+ $08c000
                |    |
                |    |
                |    |
                +----+ $08a000
                |    |	 
                |    |
                |    |	 
                +----+ $088000	 
                |    |	      CRTC12.6/7 -> 11, VIA CA2=1 
                +----+ $087000	 
                |    |	      CRTC12.6/7 -> 11, VIA CA2=0 
                +----+ $086000	 
                |    |	      CRTC12.6/7 -> 10, VIA CA2=1 
                +----+ $085000	 
                |    |	      CRTC12.6/7 -> 10, VIA CA2=0
                +----+ $084000	 
                |    |	      CRTC12.6/7 -> 01, VIA CA2=1
                +----+ $083000	 
                |    |	      CRTC12.6/7 -> 01, VIA CA2=0
                +----+ $082000	 
                |    |	      CRTC12.6/7 -> 00, VIA CA2=1
                +----+ $081000	 
                |    |	      CRTC12.6/7 -> 00, VIA CA2=0
                +----+ $080000

## Code

The code contains three modules:

- Video.vhd: the video controller part
- Clock.vhd: clock generation
- Mapper.vhd: memory mapping
- Top.vhd: glue logic and timing
- Spi.vhd: SPI module

- pinout.ucf: Pinout definition

## Build

The VHDL code is compiled using the latest version of WebISE that still supports the xc95xxx chips, i.e. version 14.7.
It can still be downloaded from the Xilinx website.

For more information on the setup, see the [build file](Build.md).

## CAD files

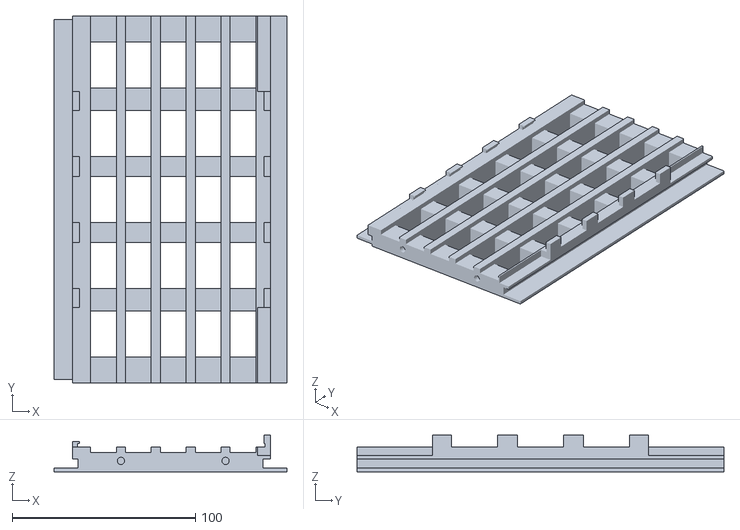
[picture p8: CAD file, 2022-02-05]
Case/kbd_support/petskey full support plate.stl
127.0 x 200.0 x 20.0

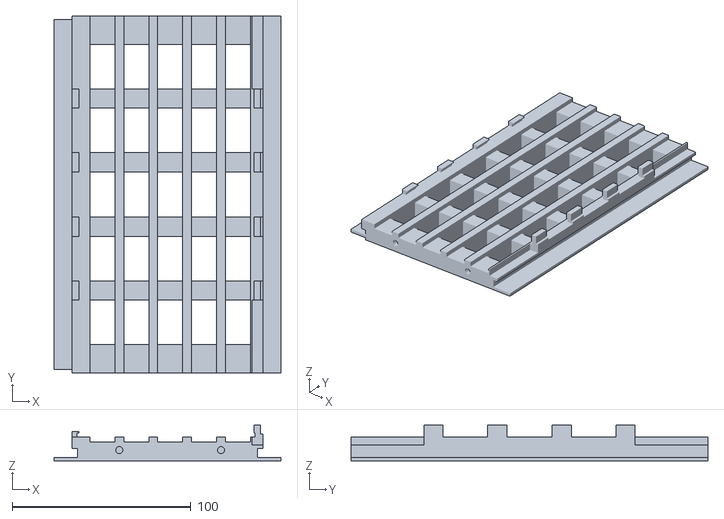
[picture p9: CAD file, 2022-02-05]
Case/kbd_support/sjg keybd full support plate.stl
127.0 x 200.0 x 20.0

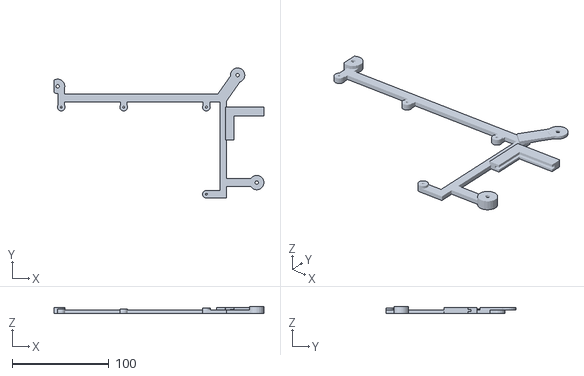
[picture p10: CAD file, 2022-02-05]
Case/board/MicroPET board mounts with batt holder.stl
217.0 x 134.5 x 7.35

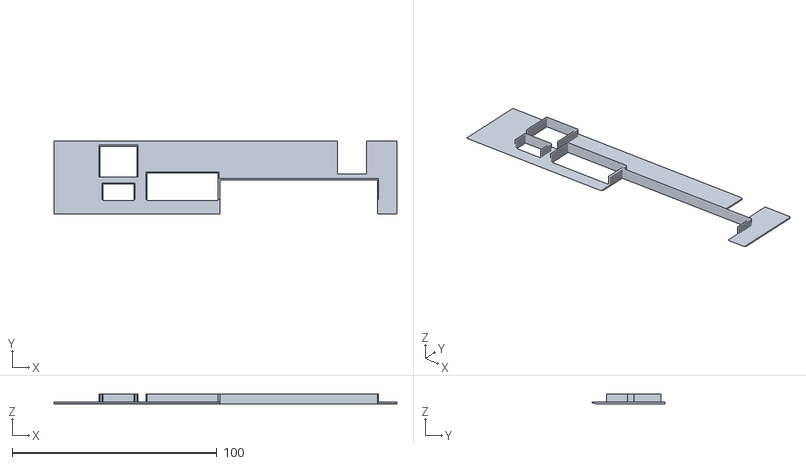
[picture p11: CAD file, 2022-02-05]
Case/board/Final MicroPET Back Cover.stl
167.5 x 35.5 x 5.00

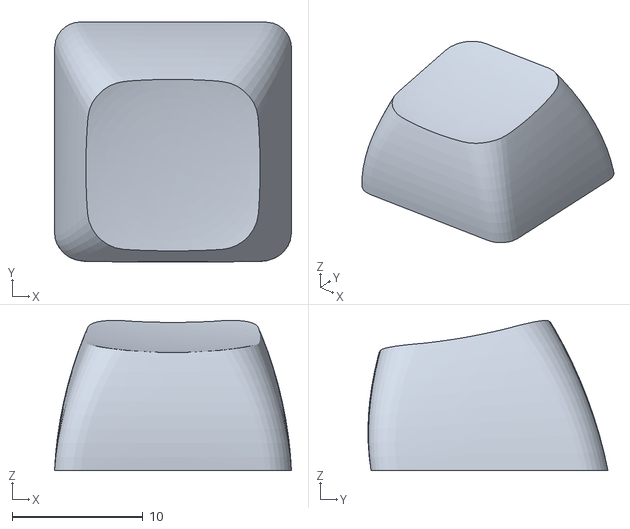
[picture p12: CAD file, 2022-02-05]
Case/keycaps/key_cbm3_w1.0.stl
18.2 x 18.4 x 11.5

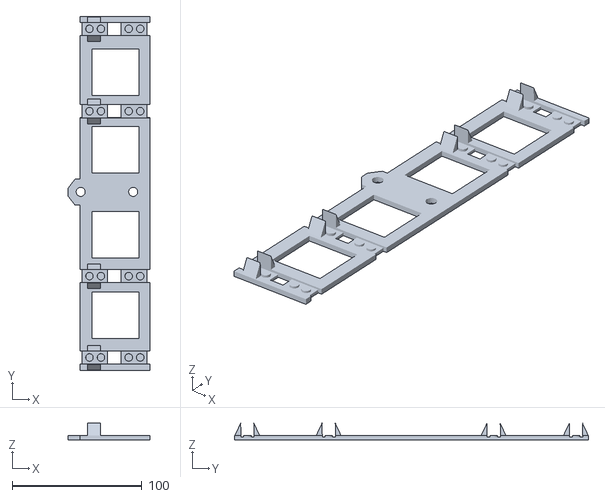
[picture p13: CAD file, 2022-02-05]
Case/kbd_support/C64c keyboard support plate.stl
63.2 x 272.5 x 12.8

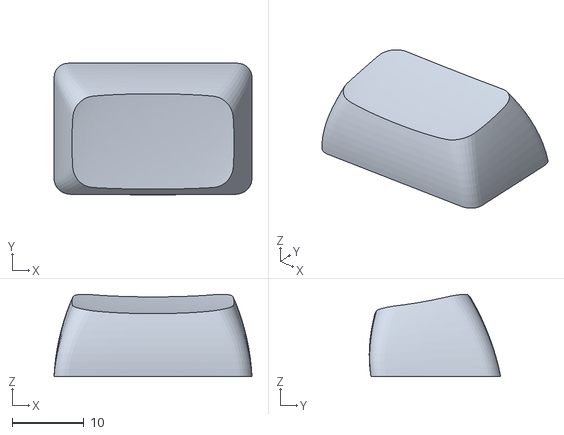
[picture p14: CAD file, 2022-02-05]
Case/keycaps/key_cbm3_w1.5.stl
27.7 x 18.4 x 11.5

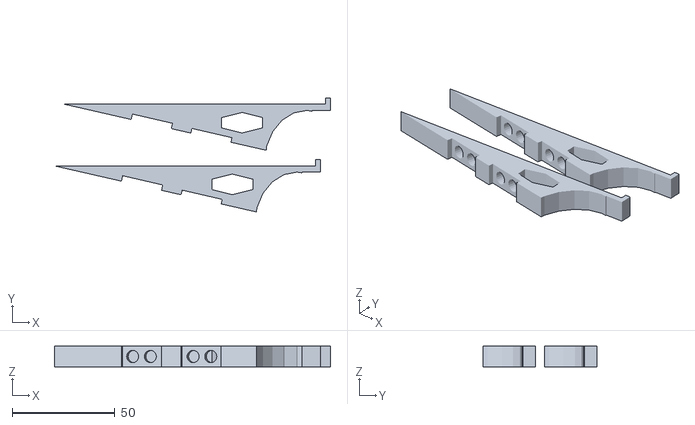
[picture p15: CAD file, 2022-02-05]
Case/kbd_support/C64 keyboard support.stl
134.2 x 55.4 x 10.0

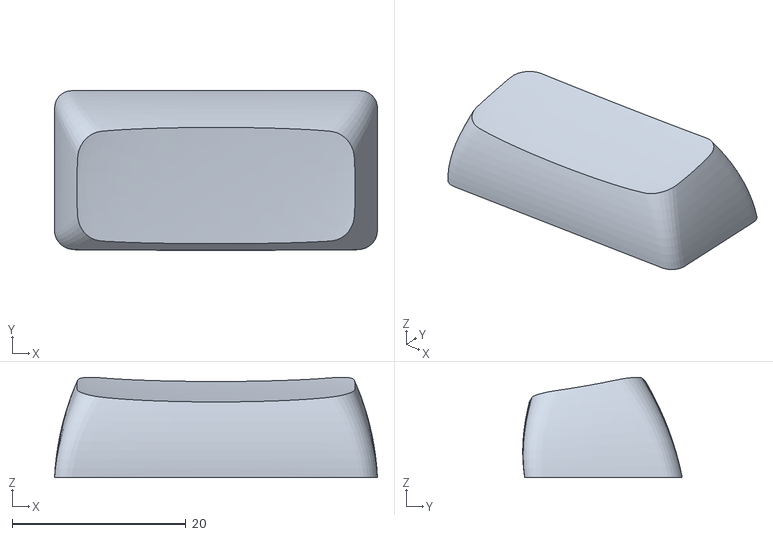
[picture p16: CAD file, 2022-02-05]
Case/keycaps/key_cbm3_w2.0.stl
37.2 x 18.4 x 11.6

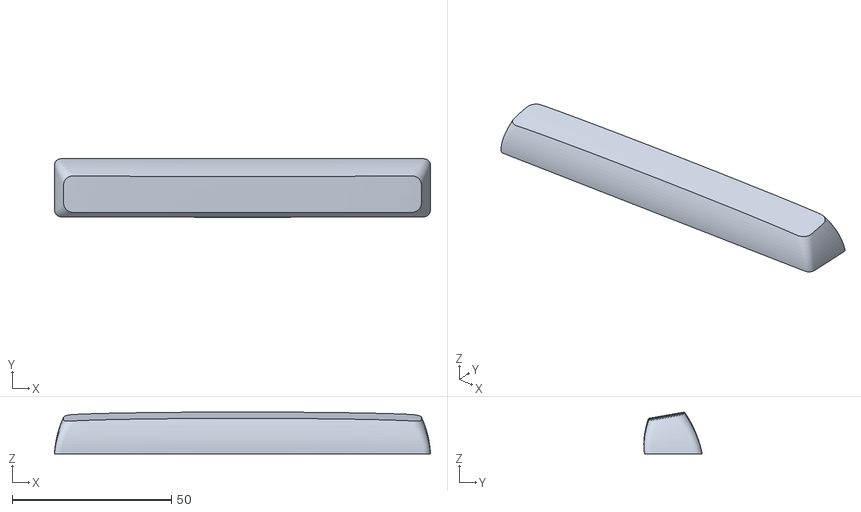
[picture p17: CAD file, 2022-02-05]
Case/keycaps/key_cbm3_s6.25.stl
118.2 x 18.4 x 13.2

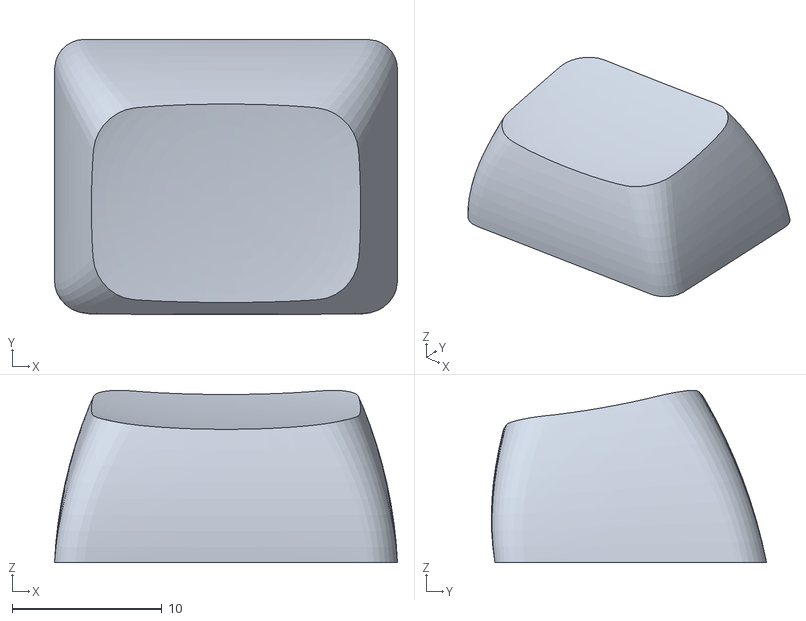
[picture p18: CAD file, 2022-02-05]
Case/keycaps/key_cbm3_w1.25.stl
22.9 x 18.4 x 11.5

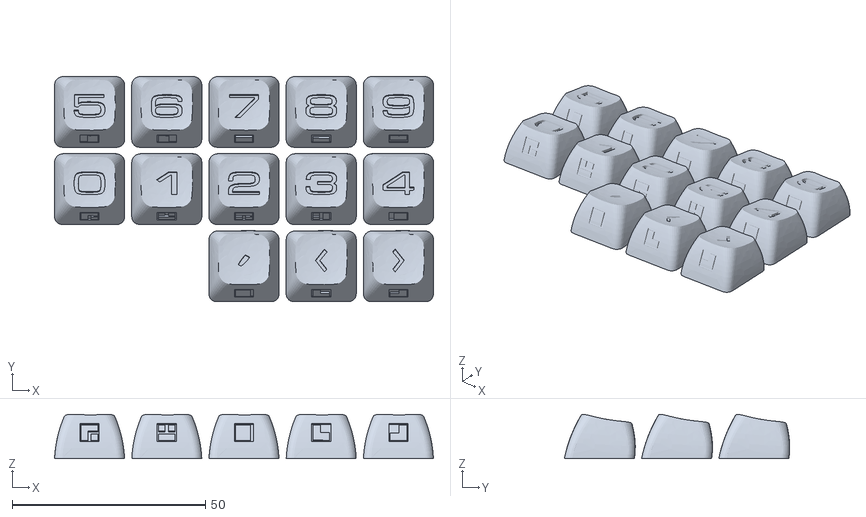
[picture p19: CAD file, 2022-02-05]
Case/keycaps/Commodore PET caps for N keyboard fine slices.stl
98.2 x 58.4 x 11.5

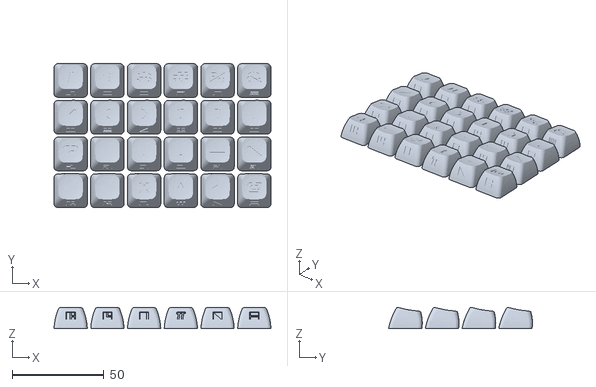
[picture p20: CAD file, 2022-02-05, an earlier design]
Case/keycaps/Commodore PET caps for N keyboard fine slices(1).stl
118.2 x 78.4 x 11.5

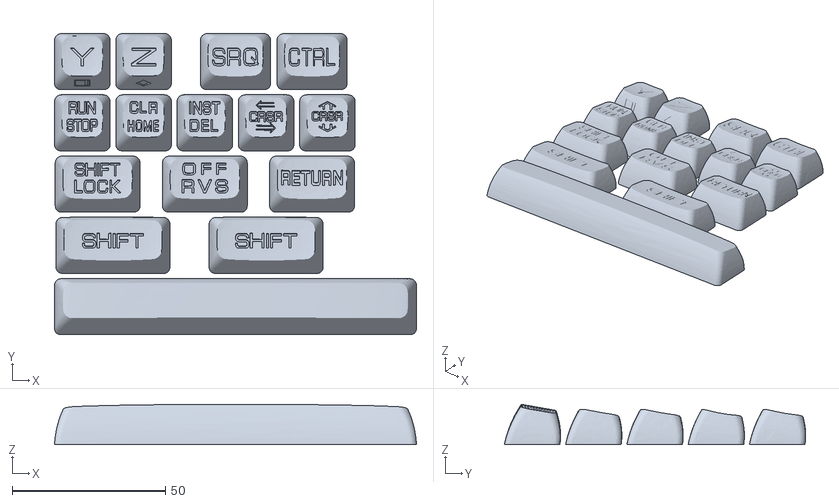
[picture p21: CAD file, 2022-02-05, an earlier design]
Case/keycaps/Commodore PET caps for N keyboard fine slices(3).stl
118.2 x 98.4 x 13.2

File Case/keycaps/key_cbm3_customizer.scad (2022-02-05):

// entry point for customizer script. This probably isn't useful to most people,
// as it's just a wrapper that helps generate customizer.scad for thingiverse.

/* [Basic-Settings] */

// what preset profile do you wish to use? disable if you are going to set paramters below
key_profile = "disable"; // [dcs, oem, dsa, sa, g20, disable]
// what key profile row is this keycap on? 0 for disable
row = 3; // [5,1,2,3,4,0]

// What does the top of your key say?
legend = "";

/* [Basic-Settings] */

// Length in units of key. A regular key is 1 unit; spacebar is usually 6.25
$key_length = 1.5; // Range not working in thingiverse customizer atm [1:0.25:16]

// What type of stem you want. Most people want Cherry.
$stem_type = "cherry";  // [cherry, alps, rounded_cherry, box_cherry, filled, disable]

// The stem is the hardest part to print, so this variable controls how much 'slop' there is in the stem
$stem_slop = 0.3; // Not working in thingiverse customizer atm [0:0.01:1]

// Font size used for text
$font_size = 6;

// Set this to true if you're making a spacebar!
$inverted_dish = false;


// Support type. default is "flared" for easy FDM printing; bars are more realistic, and flat could be for artisans
$support_type = "flared"; // [flared, bars, flat, disable]

// Supports for the stem, as it often comes off during printing. Reccommended for most machines
$stem_support_type = "tines"; // [tines, brim, disabled]

/* [Advanced] */

/* Key */
// Height in units of key. should remain 1 for most uses
$key_height = 1.0;
// Keytop thickness, aka how many millimeters between the inside and outside of the top surface of the key
$keytop_thickness = 1.5;
// Wall thickness, aka the thickness of the sides of the keycap. note this is the total thickness, aka 3 = 1.5mm walls
$wall_thickness = 4;
// Radius of corners of keycap
$corner_radius = 2;
// Width of the very bottom of the key
$bottom_key_width = 18.16;
// Height (from the front) of the very bottom of the key
$bottom_key_height = 18.16;
// How much less width there is on the top. eg top_key_width = bottom_key_width - width_difference
$width_difference = 5.5;
// How much less height there is on the top
$height_difference = 5.5;
// How deep the key is, before adding a dish
$total_depth = 11;
// The tilt of the dish in degrees. divided by key height
$top_tilt = -10;
// How skewed towards the back the top is (0 for center)
$top_skew = -2;

/* Stem */

// How far the throw distance of the switch is. determines how far the 'cross' in the cherry switch digs into the stem, and how long the keystem needs to be before supports can start. luckily, alps and cherries have a pretty similar throw. can modify to have stouter keycaps for low profile switches, etc
$stem_throw = 4;
// Diameter of the outside of the rounded cherry stem
$rounded_cherry_stem_d = 5.5;


// How much higher the stem is than the bottom of the keycap.
// Inset stem requires support but is more accurate in some profiles
$stem_inset = 0;
// How many degrees to rotate the stems. useful for sideways keycaps, maybe
$stem_rotation = 0;

/* Shape */

// Key shape type, determines the shape of the key. default is 'rounded square'
$key_shape_type = "sculpted_square";
//$key_shape_type = "rounded_square";
// ISO enter needs to be linear extruded NOT from the center. this tells the program how far up 'not from the center' is
$linear_extrude_height_adjustment = 0;
// How many slices will be made, to approximate curves on corners. Leave at 1 if you are not curving corners
// If you're doing fancy bowed keycap sides, this controls how many slices you take
$height_slices = 9;

/* Dish */

// What type of dish the key has. note that unlike stems and supports a dish ALWAYS gets rendered.
$dish_type = "spherical"; // [cylindrical, spherical, sideways cylindrical, old spherical, disable]
// How deep the dish 'digs' into the top of the keycap. this is max depth, so you can't find the height from total_depth - dish_depth. besides the top is skewed anyways
$dish_depth = 1.2;
// How skewed in the x direction the dish is
$dish_skew_x = 0;
// How skewed in the y direction (height) the dish is
$dish_skew_y = 0;
// If you need the dish to extend further, you can 'overdraw' the rectangle it will hit
$dish_overdraw_width = 0;
// Same as width but for height
$dish_overdraw_height = 0;

/* Misc */
// There's a bevel on the cherry stems to aid insertion / guard against first layer squishing making a hard-to-fit stem.
$cherry_bevel = true;

// How tall in mm the stem support is, if there is any. stem support sits around the keystem and helps to secure it while printing.
$stem_support_height = 0.4;
// Font used for text
$font="DejaVu Sans Mono:style=Book";
// Whether or not to render fake keyswitches to check clearances
$clearance_check = false;
// Use linear_extrude instead of hull slices to make the shape of the key
// Should be faster, also required for concave shapes
$linear_extrude_shape = false;
//should the key be rounded? unnecessary for most printers, and very slow
$rounded_key = false;
//minkowski radius. radius of sphere used in minkowski sum for minkowski_key function. 1.75 for G20
$minkowski_radius = .33;

/* Features */

//insert locating bump
$key_bump = false;
//height of the location bump from the top surface of the key
$key_bump_depth = 0.5;
//distance to move the bump from the front edge of the key
$key_bump_edge = 0.4;

/* [Hidden] */

//list of legends to place on a key format: [text, halign, valign, size]
//halign = "left" or "center" or "right"
//valign = "top" or "center" or "bottom"
// Currently does not work with thingiverse customizer, and actually breaks it
$legends = [];

// Dimensions of alps stem
$alps_stem = [4.45, 2.25];

// Enable stabilizers. If you don't want stabilizers use disable; most other keycaps use Cherry stabilizers
$stabilizer_type = "cherry"; // [cherry, rounded_cherry, alps, disable]

// Ternaries are ONLY for customizer. they will NOT work if you're using this in
// OpenSCAD. you should use stabilized(), openSCAD customizer,
// or set $stabilizers directly
// Array of positions of stabilizers
$stabilizers = $key_length >= 6 ? [[-50, 0], [50, 0]] : $key_length >= 2 ? [[-12,0],[12,0]] : [];

// Where the stems are in relation to the center of the keycap, in units. default is one in the center
// Shouldn't work in thingiverse customizer, though it has been...
$stem_positions = [[0,0]];

// key width functions

module u(u=1) {
  $key_length = u;
  children();
}

module 1u() {
  u(1) children();
}

module 1_25u() {
  u(1.25) children();
}

module 1_5u() {
  u(1.5) children();
}

module 2u() {
  u(2) children();
}

module 2_25u() {
  u(2.25) children();
}

module 2_75u() {
  u(2.75) children();
}

module 6_25u() {
  u(6.25) children();
}

// key height functions

module uh(u=1) {
  $key_height = u;
  children();
}

module 1uh() {
  uh(1) children();
}

module 2uh() {
  uh(2) children();
}

module 1_25uh() {
  uh(1.25) children();
}

module 1_5uh() {
  uh(1.5) children();
}

module 2_25uh() {
  uh(2.25) children();
}

module 2_75uh() {
  uh(2.75) children();
}

module 6_25uh() {
  uh(6.25) children();
}
// key profile definitions

// unlike the other files with their own dedicated folders, this one doesn't
// need a selector. I wrote one anyways for customizer support though
module dcs_row(n=3) {
  // names, so I don't go crazy
  $bottom_key_width = 18.16;
  $bottom_key_height = 18.16;
  $width_difference = 6;
  $height_difference = 4;
  $dish_type = "cylindrical";
  $dish_depth = 1;
  $dish_skew_x = 0;
  $dish_skew_y = 0;
  $top_skew = 1.75;

  if (n == 5) {
    $total_depth = 11.5;
    $top_tilt = -6;
    children();
  } else if (n == 1) {
    $total_depth = 8.5;
    $top_tilt = -1;
    children();
  } else if (n == 2) {
    $total_depth = 7.5;
    $top_tilt = 3;
    children();
  } else if (n == 3) {
    $total_depth = 6;
    $top_tilt = 7;
    children();
  } else if (n == 4) {
    $total_depth = 6;
    $top_tilt = 16;
    children();
  } else {
    children();
  }
}
module oem_row(n=3) {
  $bottom_key_width = 18.05;
  $bottom_key_height = 18.05;
  $width_difference = 5.8;
  $height_difference = 4;
  $dish_type = "cylindrical";
  $dish_depth = 1;
  $dish_skew_x = 0;
  $dish_skew_y = 0;
  $top_skew = 1.75;
  $stem_inset = 1.2;
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

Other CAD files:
Case/keycaps/Commodore PET caps for N keyboard fine slices(2).stl

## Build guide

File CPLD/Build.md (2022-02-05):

# Build setup for the CPLD

## WebISE

The xc95xxx CPLDs are only supported by the WebISE software available for download from Xilinx.
Support has not (yet to my knowledge) been integrated into their new Vivado software.

### Setting up the project

When you start WebISE, you have to create a new project. 

Use this CPLD folder as project folder, and a "work" subfolder as work folder. It is better not to use the same folder, as 
in the work folder many files are created that clutter the folder only.

Then setup the project as shown in this images

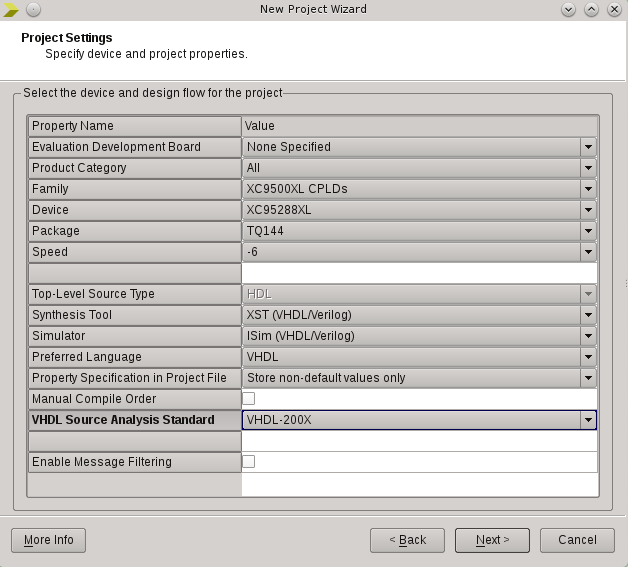
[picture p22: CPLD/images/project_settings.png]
Project Settings


Under the project, "Add Source" and add the "Top.vhd" VHDL file

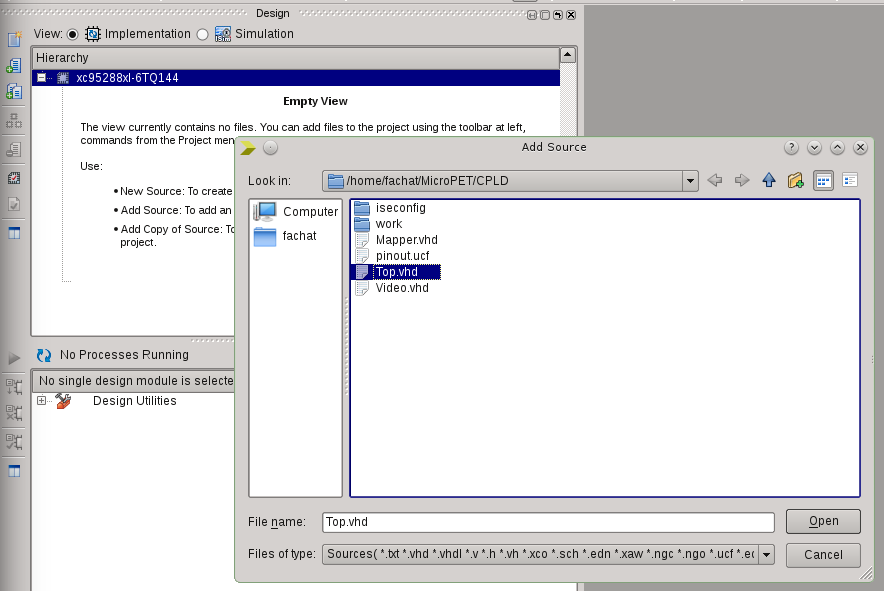
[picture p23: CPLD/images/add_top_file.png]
Add Top VHDL file


Then add the other VHDL files underneath by assigning the VHDL files to their respective components.
Note that for the Video and Clock components, two options are available, Composite video out or VGA (640x480) output.

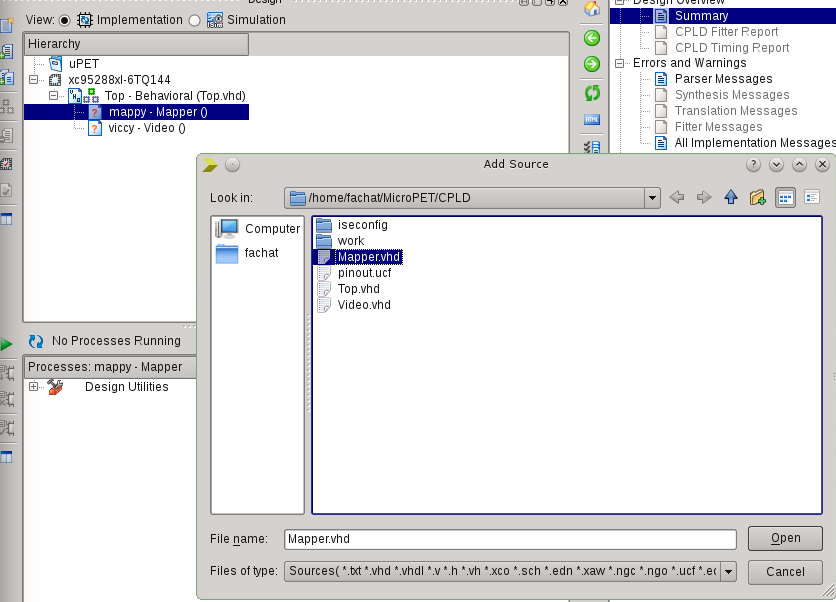
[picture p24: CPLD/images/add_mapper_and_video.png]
Add other VHDL files


Finally, add the constraints file

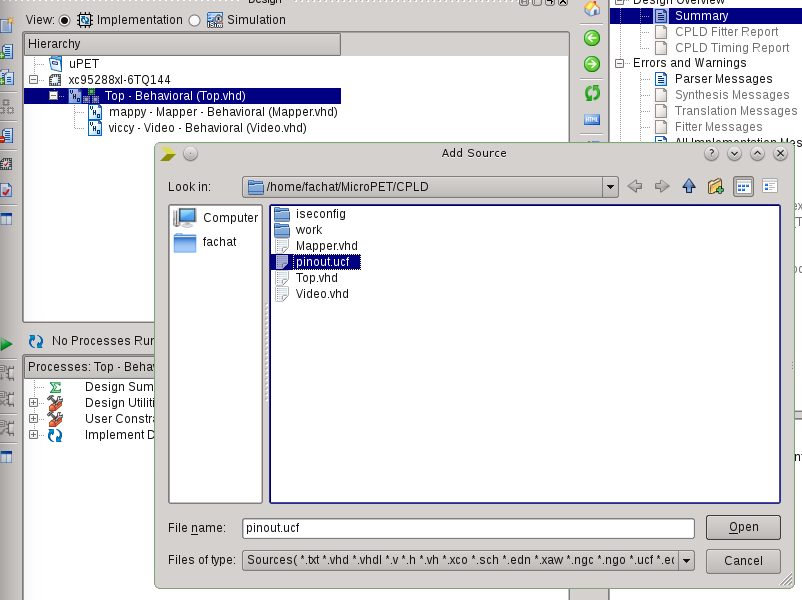
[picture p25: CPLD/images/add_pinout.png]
Add Pinout


In the process properties, set "Area" as optimization goal, and optimization effort to "High".

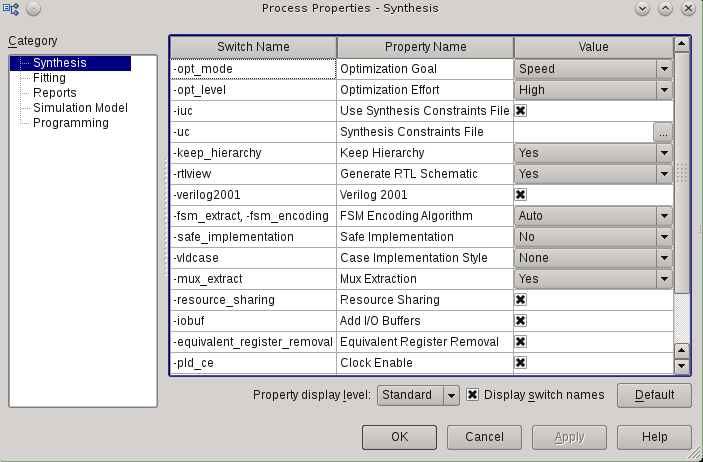
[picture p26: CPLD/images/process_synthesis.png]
Synthesis properties


Set "Optimize Density" for the Fitting.

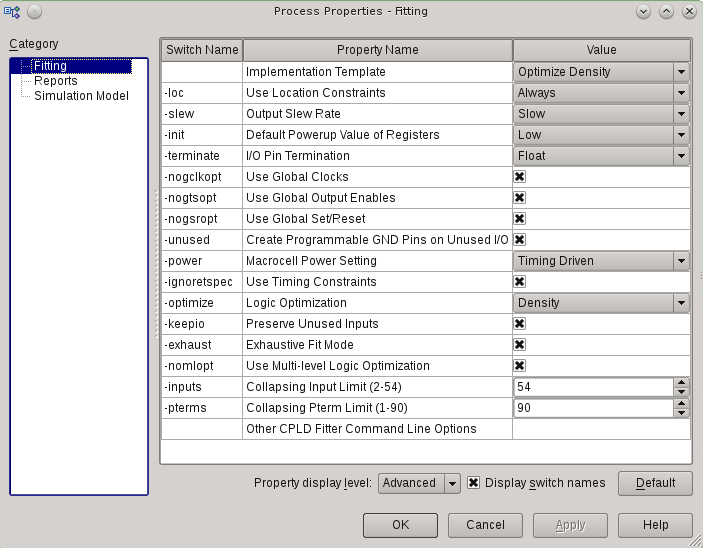
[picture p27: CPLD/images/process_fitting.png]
Fitting properties


Also, enable "advanced" build properties, and click "extensive fitting", to allow for slower, but better fitting.
The r2 managed to be fitted with pterm limit: 12 and input limit: 17 - so this may be a worth a try to shorten
the fitting time (with full levels it took over 2-3h...).

Then you can build the "Top.jed" file by clicking the green triangle to start the build.

### Programming the CPLD

To program the CPLD, the "iMPACT" tool is used, that is part of the WebISE package.

Here you have to create a new project too.

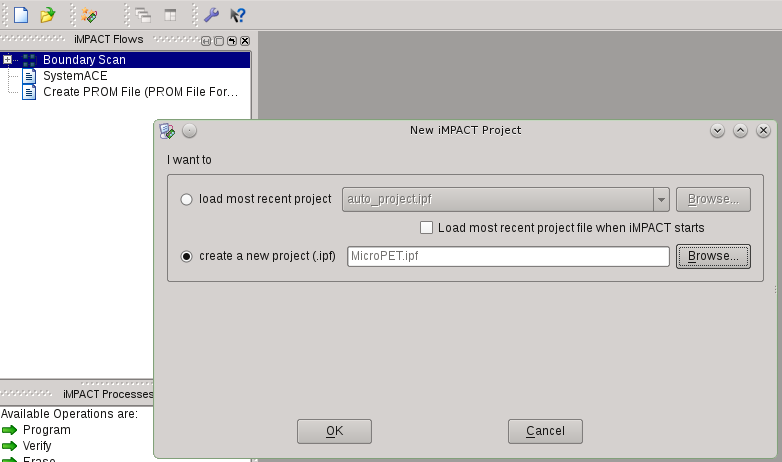
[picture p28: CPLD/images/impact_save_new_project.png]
iMPACT project


Connect the USB JTAG cable to the PC, attach the JTAG wires to the probe connector on the Micro-PET board, and power it up.
Then let iMPACT automatically detect the CPLD

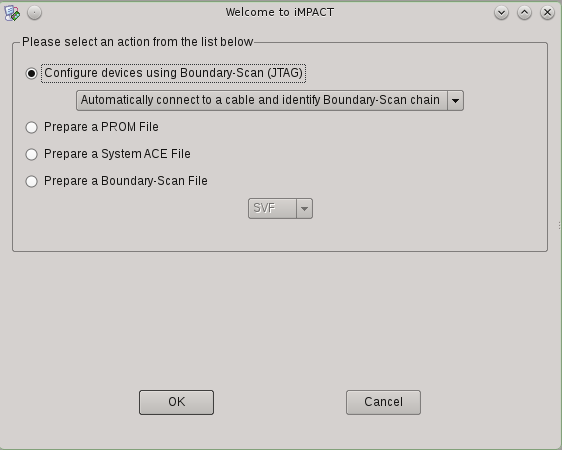
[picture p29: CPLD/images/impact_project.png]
Detecting the CPLD


It may be possible to use other cables, to set them up use the Output/Device Setup menu

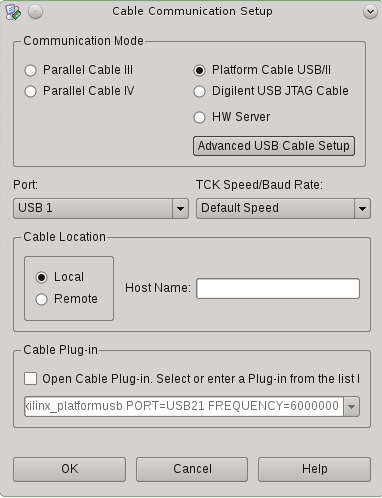
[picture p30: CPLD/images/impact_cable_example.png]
iMPACT cable setup


Right-clicking on the Device and reading the Device ID is a good check if the cable works

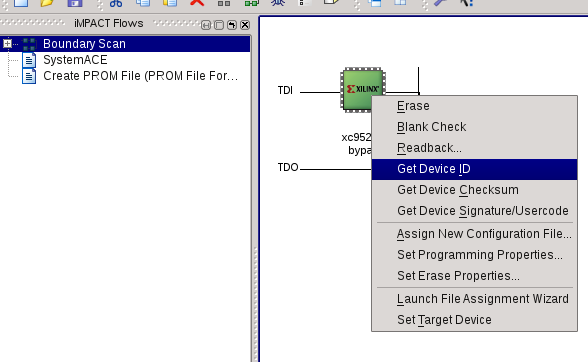
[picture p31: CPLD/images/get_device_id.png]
iMPACT cable check


Then assign a configuration file to the CPLD

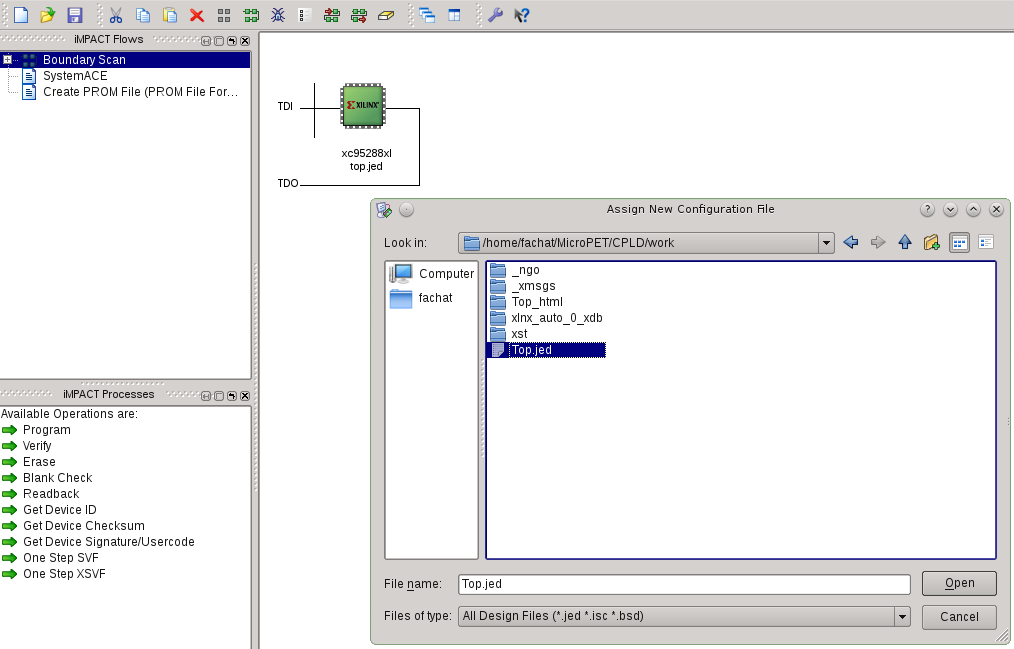
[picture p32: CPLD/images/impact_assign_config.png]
Assign configuration


After that, you can right-click on the CPLD device on display and select "Program" to program the configuration into the CPLD.

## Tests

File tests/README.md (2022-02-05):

# Unit tests

## virtpet

This little test program shows the mapping features for the lower 32k, as well as the video memory window (where the
$8xxx area in CPU address space is mapped to video memory). 
It installs itself as a terminate-and-stay-resident (TSR), and checks when both SHIFT keys are pressed at the same time.
It then switches to the next of a total of four "virtual" PETs.

## low32k / map

These tests check the functionality to re-map the low 32k in bank 0 CPU address space into one of 16 32k-banks
in the 512k RAM chip.

### low32k 

This writes a signature into (almost) every block in each bank, and checks in a second pass if none of the
signatures have been overwritten.

Note that it will mangle the system font, as it writes the RAM signature there as well.

### map

This are (will be) small routines that can be used from the machine language monitor to fill / exchange 
data from other banks.

## ROM tests

### readflash

Reads the flash memory from BASIC

### romtest

- romtest01(a).a65: This test program fills bank 1 continuously with an increasing value. This can be used to check the hires mode. The output o
f its build has to be copied into the top 4k of the ROM to boot/run
- romtest02(a).a65: This test program copies an 8k character ROM image from start of the ROM to start of bank 7, where the video code takes its 
character information. Then fills the character screen, and continuously increase the value in the character screen at $008000. This tests the c
haracter display output. The output of its build has to be copied into the top 4k of the ROM to boot/run

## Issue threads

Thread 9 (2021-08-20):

power

sp00ck, 2021-08-20:
Is possible put lipo or AA power?
mobile device CPET will be incredible. Small processor == need small power

sp00ck, 2021-09-07:
You sugest MPet use more power than cell phone?

fachat, 2021-09-13:
The Micro-PET R2 uses - without Ethernet or USB attached - uses 0.55A at 5V, i.e. around 2.75W.
The original PET has two power regulators, each rated at 1.5A with 5V, so between 7.5 and 15W (ignoring 12V / -5V, and monitor not included as with the Micro-PET)
So, the Micro-PET is 12 times faster, and uses around 1/3 the power - an efficiency gain of x36.

A modern smartphone seems to be using .5-1W depending on usage profile, even without screen backlight in some situation, as far as I can read e.g. from https://www.usenix.org/legacy/event/usenix10/tech/full_papers/Carroll.pdf

So, the Micro-PET does indeed use more energy than a modern smartphone, but not as much as I actually assumed.
You could probably reduce the wattage by going to full 3.3V, but that would sacrifice the compatibility with the IEEE488 bus.

A random smartphone battery I found has 3.8V, and 8Wh (2100mAh) - so that would be about 2.1Ah at 3.8V, or around 3.8h at .55A for a Micro-PET. So I guess with this battery you could run it for about 3-4 hours - without a screen though.

A case that contains a Micro-PET and full size keyboard should provide enough space to hold two or even more of these batteries to supply the screen and extend the runtime.

Do you have a suggestion for a nice VGA-compatible mobile display with low power consumption?

sp00ck, 2021-09-16:
Many thanks. Very interesting information.

Closed 2022-03-14.

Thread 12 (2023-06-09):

BOM missing SMD parts

Sch-LikA, 2023-06-09:
I am finally starting to assemble my uPET, only to discover that the BOM is missing all SMD components. What is more, there is no part id for the RAM module, would be nice to have one. Would be nice to update it.

Thanks !!

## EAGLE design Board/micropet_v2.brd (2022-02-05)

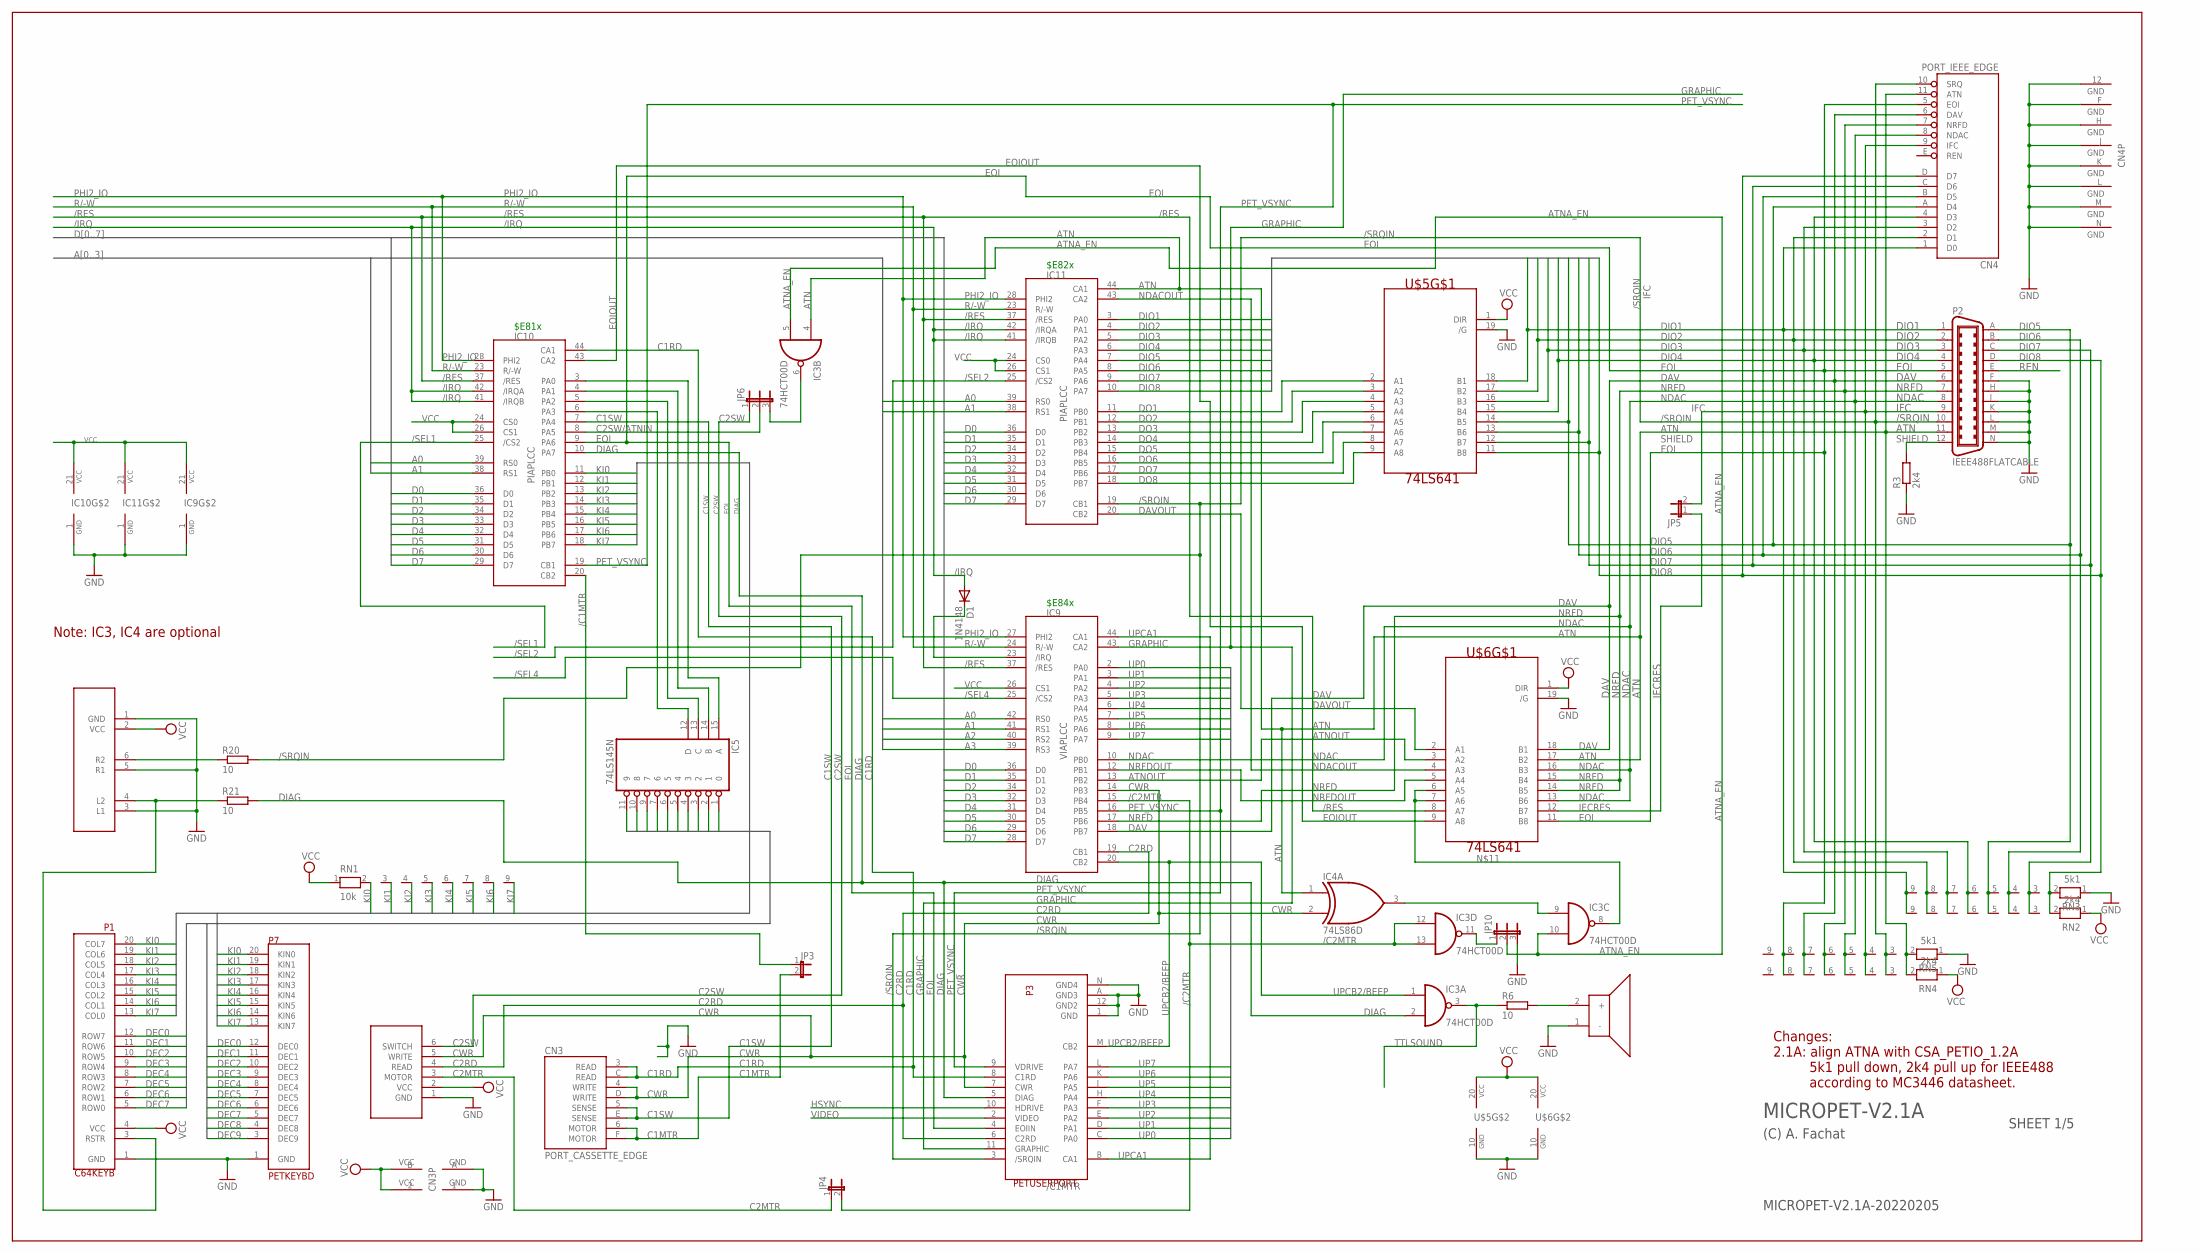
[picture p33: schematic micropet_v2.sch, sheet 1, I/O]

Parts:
BEEP1: PIEZOBEEPER; JP2
CN3: PORT_CASSETTE_EDGE; MA156_6-2_KEYED
CN4: PORT_IEEE_EDGE; MA156_12-2_IEEE
D1: 1N4148; D-5
IC3: 74HCT00D; SO14
IC4: 74LS86D; SO14
IC5: 74LS145N; DIL16
IC9: VIAPLCC; PLCC44
IC10, IC11: PIAPLCC; PLCC44
JP3, JP4, JP5: JP1E; JP1
JP6, JP10: JP2E; JP2
P1: C64KEYB
P2: IEEE488FLATCABLE; FLAT24
P3: PETUSERPORT; FLAT24
P6: CBMTAPE; JP6
P7: PETKEYBD; C64KEYB
R3: 2k4; 0207/2V
R6, R20, R21: 10; 0207/2V
RN1: 10k; RN-9
RN2, RN4: 2k4; RN-9
RN3, RN5: 5k1; RN-9
U$5, U$6: 74LS641; DIL20
U$11: PETSKEY_EXTRA; JP6

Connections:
/C1MTR: IC10.20 (CB2), JP3.1
/C2MTR: IC3.12 (I0), IC3.13 (I1), IC9.15 (PB4), JP4.2
/IRQ: D1.A, IC10.41 (/IRQB), IC10.42 (/IRQA), IC11.41 (/IRQB), IC11.42 (/IRQA); also elsewhere on the board
/RES: IC9.37 (/RES), IC10.37 (/RES), IC11.37 (/RES), U$6.8 (A7); also elsewhere on the board
/SEL1: IC10.25 (/CS2); also elsewhere on the board
/SEL2: IC11.25 (/CS2); also elsewhere on the board
/SEL4: IC9.25 (/CS2); also elsewhere on the board
/SRQIN: CN4.10 (SRQ), IC11.19 (CB1), P2.10, P3.3 (/SRQIN), R20.2, RN4.3, RN5.3
A0: IC9.42 (RS0), IC10.39 (RS0), IC11.39 (RS0); also elsewhere on the board
A1: IC9.41 (RS1), IC10.38 (RS1), IC11.38 (RS1); also elsewhere on the board
A2: IC9.40 (RS2); also elsewhere on the board
A3: IC9.39 (RS3); also elsewhere on the board
ATN: CN4.11 (ATN), IC3.4 (I0), IC4.1 (I0), IC11.44 (CA1), P2.11, RN4.2, RN5.2, U$6.17 (B2)
ATNA_EN: IC3.5 (I1), IC3.10 (I1), JP10.2
ATNOUT: IC9.13 (PB2), U$6.3 (A2)
C1MTR: CN3.6 (MOTOR), CN3.F (MOTOR), JP3.2
C1RD: CN3.3 (READ), CN3.C (READ), IC10.44 (CA1), P3.8 (C1RD)
C1SW: CN3.5 (SENSE), CN3.E (SENSE), IC10.7 (PA4)
C2MTR: JP4.1, P6.3 (MOTOR)
C2RD: IC9.19 (CB1), P3.6 (C2RD), P6.4 (READ)
C2SW: JP6.1, P6.6 (SWITCH)
C2SW/ATNIN: IC10.8 (PA5), JP6.2
CWR: CN3.4 (WRITE), CN3.D (WRITE), IC4.2 (I1), IC9.14 (PB3), P3.7 (CWR), P6.5 (WRITE)
D0: IC9.36 (D0), IC10.36 (D0), IC11.36 (D0); also elsewhere on the board
D1: IC9.35 (D1), IC10.35 (D1), IC11.35 (D1); also elsewhere on the board
D2: IC9.34 (D2), IC10.34 (D2), IC11.34 (D2); also elsewhere on the board
D3: IC9.32 (D3), IC10.33 (D3), IC11.33 (D3); also elsewhere on the board
D4: IC9.31 (D4), IC10.32 (D4), IC11.32 (D4); also elsewhere on the board
D5: IC9.30 (D5), IC10.31 (D5), IC11.31 (D5); also elsewhere on the board
D6: IC9.29 (D6), IC10.30 (D6), IC11.30 (D6); also elsewhere on the board
D7: IC9.28 (D7), IC10.29 (D7), IC11.29 (D7); also elsewhere on the board
DAV: CN4.6 (DAV), IC9.18 (PB7), P2.6, RN4.7, RN5.7, U$6.18 (B1)
DAVOUT: IC11.20 (CB2), U$6.2 (A1)
DEC0: IC5.1 (0), P1.12 (ROW7), P7.12 (DEC0)
DEC1: IC5.2 (1), P1.11 (ROW6), P7.11 (DEC1)
DEC2: IC5.3 (2), P1.10 (ROW5), P7.10 (DEC2)
DEC3: IC5.4 (3), P1.9 (ROW4), P7.9 (DEC3)
DEC4: IC5.5 (4), P1.8 (ROW3), P7.8 (DEC4)
DEC5: IC5.6 (5), P1.7 (ROW2), P7.7 (DEC5)
DEC6: IC5.7 (6), P1.6 (ROW1), P7.6 (DEC6)
DEC7: IC5.9 (7), P1.5 (ROW0), P7.5 (DEC7)
DEC8: IC5.10 (8), P7.4 (DEC8)
DEC9: IC5.11 (9), P7.3 (DEC9)
DIAG: IC3.2 (I1), IC10.10 (PA7), P3.5 (DIAG), R21.2
DIO1: CN4.1 (D0), IC11.3 (PA0), P2.1, RN2.9, RN3.9, U$5.18 (B1)
DIO2: CN4.2 (D1), IC11.4 (PA1), P2.2, RN2.8, RN3.8, U$5.17 (B2)
DIO3: CN4.3 (D2), IC11.5 (PA2), P2.3, RN2.7, RN3.7, U$5.16 (B3)
DIO4: CN4.4 (D3), IC11.6 (PA3), P2.4, RN2.6, RN3.6, U$5.15 (B4)
DIO5: CN4.A (D4), IC11.7 (PA4), P2.A (13), RN2.5, RN3.5, U$5.14 (B5)
DIO6: CN4.B (D5), IC11.8 (PA5), P2.B (14), RN2.4, RN3.4, U$5.13 (B6)
DIO7: CN4.C (D6), IC11.9 (PA6), P2.C (15), RN2.3, RN3.3, U$5.12 (B7)
DIO8: CN4.D (D7), IC11.10 (PA7), P2.D (16), RN2.2, RN3.2, U$5.11 (B8)
DO1: IC11.11 (PB0), U$5.2 (A1)
DO2: IC11.12 (PB1), U$5.3 (A2)
DO3: IC11.13 (PB2), U$5.4 (A3)
DO4: IC11.14 (PB3), U$5.5 (A4)
DO5: IC11.15 (PB4), U$5.6 (A5)
DO6: IC11.16 (PB5), U$5.7 (A6)
DO7: IC11.17 (PB6), U$5.8 (A7)
DO8: IC11.18 (PB7), U$5.9 (A8)
EOI: CN4.5 (EOI), IC10.9 (PA6), P2.5, P3.4 (EOIIN), RN4.8, RN5.8, U$6.11 (B8)
EOIOUT: IC10.43 (CA2), U$6.9 (A8)
GND: BEEP1.1 (-), CN3.1 (GND), CN3.A (GND), CN4.12 (GND), CN4.F (GND), CN4.H (GND), CN4.J (GND), CN4.K (GND), CN4.L (GND), CN4.M (GND), CN4.N (GND), IC3.7 (GND), IC4.7 (GND), IC5.8 (GND), IC9.1 (GND), IC10.1 (GND), IC11.1 (GND), JP10.3, P1.1 (GND), P2.F (18), P2.H (19), P2.J (20), P2.K (21), P2.L (22), P2.M (23), P2.N (24), P3.1 (GND), P3.12 (GND2), P3.A (GND3), P3.N (GND4), P6.1 (GND), P7.1 (GND), R3.1, RN3.1, RN5.1, U$5.10 (GND), U$5.19 (/G), U$6.10 (GND), U$6.19 (/G), U$11.1 (GND), U$11.3 (L1), U$11.5 (R1); also elsewhere on the board
GRAPHIC: IC9.43 (CA2), P3.11 (GRAPHIC); also elsewhere on the board
HSYNC: P3.10 (HDRIVE); also elsewhere on the board
IECRES: JP5.1, U$6.12 (B7)
IFC: CN4.9 (IFC), JP5.2, P2.9, RN4.4, RN5.4
KI0: IC10.11 (PB0), P1.20 (COL7), P7.20 (KIN0), RN1.2
KI1: IC10.12 (PB1), P1.19 (COL6), P7.19 (KIN1), RN1.3
KI2: IC10.13 (PB2), P1.18 (COL5), P7.18 (KIN2), RN1.4
KI3: IC10.14 (PB3), P1.17 (COL4), P7.17 (KIN3), RN1.5
KI4: IC10.15 (PB4), P1.16 (COL3), P7.16 (KIN4), RN1.6
KI5: IC10.16 (PB5), P1.15 (COL2), P7.15 (KIN5), RN1.7
KI6: IC10.17 (PB6), P1.14 (COL1), P7.14 (KIN6), RN1.8
KI7: IC10.18 (PB7), P1.13 (COL0), P7.13 (KIN7), RN1.9
unnamed: IC3.9 (I0), IC4.3 (O)
unnamed: IC3.11 (O), JP10.1
unnamed: BEEP1.2 (+), R6.2
unnamed: D1.C, IC9.23 (/IRQ)
unnamed: IC3.8 (O), U$6.6 (A5), U$6.7 (A6)
unnamed: IC3.6 (O), JP6.3
unnamed: IC5.15 (A), IC10.3 (PA0)
unnamed: IC5.14 (B), IC10.4 (PA1)
unnamed: IC5.13 (C), IC10.5 (PA2)
unnamed: IC5.12 (D), IC10.6 (PA3)
unnamed: P1.3 (RSTR), R21.1, U$11.4 (L2)
unnamed: R20.1, U$11.6 (R2)
NDAC: CN4.8 (NDAC), IC9.10 (PB0), P2.8, RN4.5, RN5.5, U$6.13 (B6), U$6.16 (B3)
NDACOUT: IC11.43 (CA2), U$6.4 (A3)
NRFD: CN4.7 (NRFD), IC9.17 (PB6), P2.7, RN4.6, RN5.6, U$6.14 (B5), U$6.15 (B4)
NRFDOUT: IC9.12 (PB1), U$6.5 (A4)
PET_VSYNC: IC9.16 (PB5), IC10.19 (CB1), P3.9 (VDRIVE); also elsewhere on the board
PHI2_IO: IC9.27 (PHI2), IC10.28 (PHI2), IC11.28 (PHI2); also elsewhere on the board
R/-W: IC9.24 (R/-W), IC10.23 (R/-W), IC11.23 (R/-W); also elsewhere on the board
REN: P2.E (17)
SHIELD: P2.12, R3.2
TTLSOUND: IC3.3 (O), R6.1; also elsewhere on the board
UP0: IC9.2 (PA0), P3.C (PA0)
UP1: IC9.3 (PA1), P3.D (PA1)
UP2: IC9.4 (PA2), P3.E (PA2)
UP3: IC9.5 (PA3), P3.F (PA3)
UP4: IC9.6 (PA4), P3.H (PA4)
UP5: IC9.7 (PA5), P3.J (PA5)
UP6: IC9.8 (PA6), P3.K (PA6)
UP7: IC9.9 (PA7), P3.L (PA7)
UPCA1: IC9.44 (CA1), P3.B (CA1)
UPCB2/BEEP: IC3.1 (I0), IC9.20 (CB2), P3.M (CB2)
VCC: CN3.2 (VCC), CN3.B (VCC), IC3.14 (VCC), IC4.14 (VCC), IC5.16 (VCC), IC9.21 (VCC), IC9.26 (CS1), IC10.21 (VCC), IC10.24 (CS0), IC10.26 (CS1), IC11.21 (VCC), IC11.24 (CS0), IC11.26 (CS1), P1.4 (VCC), P6.2 (VCC), RN1.1, RN2.1, RN4.1, U$5.1 (DIR), U$5.20 (VCC), U$6.1 (DIR), U$6.20 (VCC), U$11.2 (VCC); also elsewhere on the board
VIDEO: P3.2 (VIDEO); also elsewhere on the board

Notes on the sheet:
MICROPET-V2.1A-20220205
MICROPET-V2.1A
(C) A. Fachat
$E82x
$E84x
$E81x
SHEET 1/5
Note: IC3, IC4 are optional
Changes: 2.1A: align ATNA with CSA_PETIO_1.2A 5k1 pull down, 2k4 pull up for IEEE488 according to MC3446 datasheet.

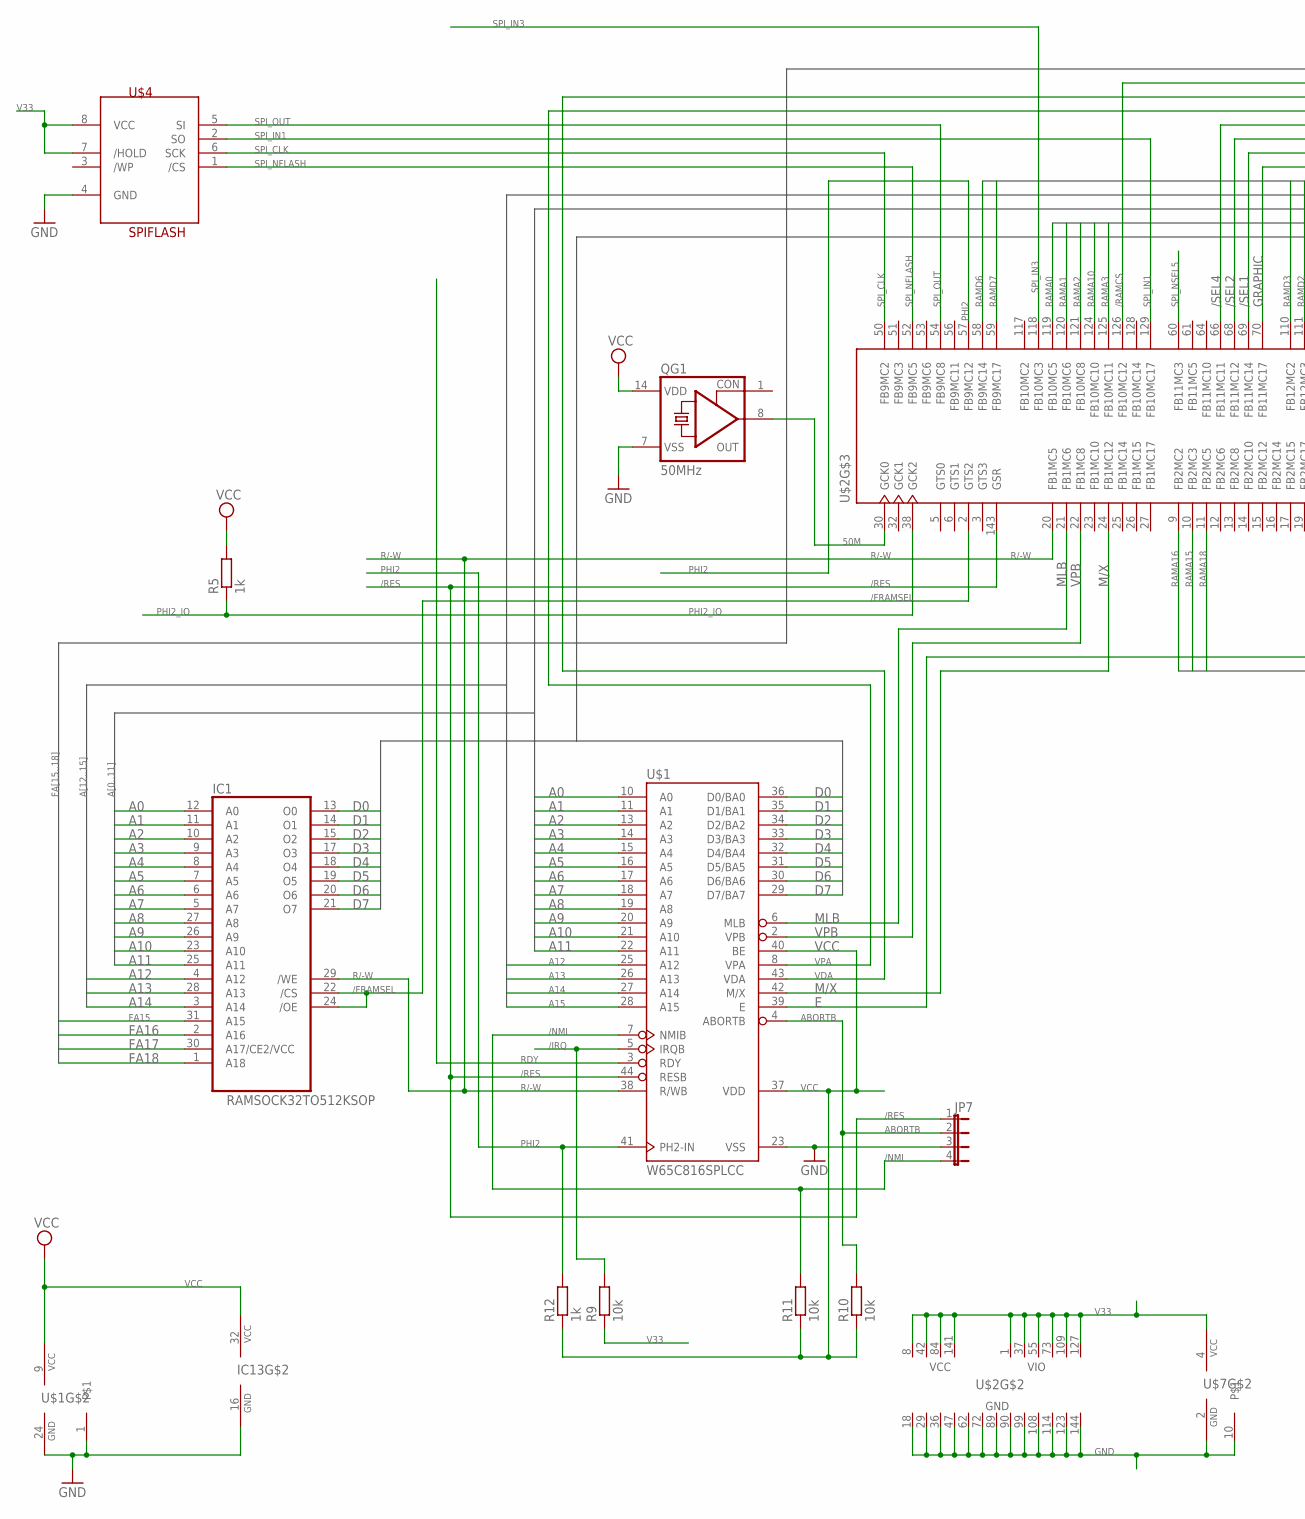
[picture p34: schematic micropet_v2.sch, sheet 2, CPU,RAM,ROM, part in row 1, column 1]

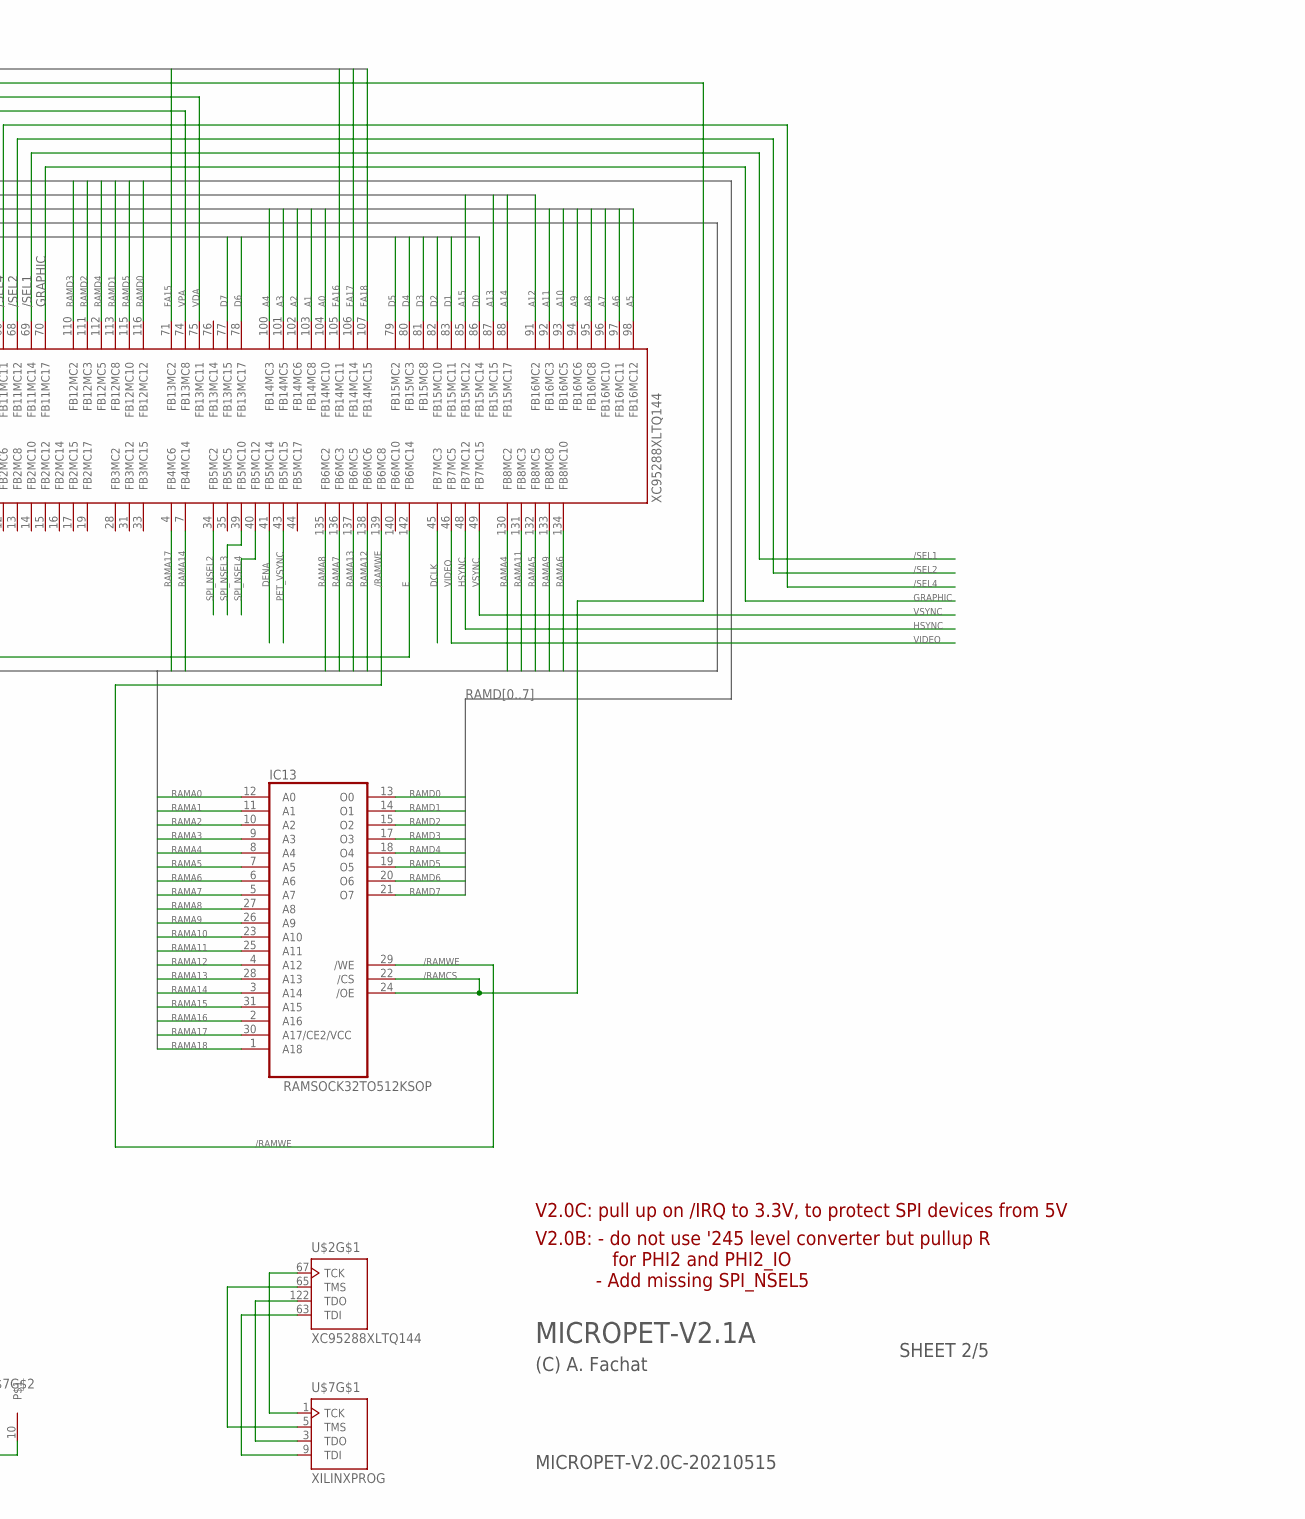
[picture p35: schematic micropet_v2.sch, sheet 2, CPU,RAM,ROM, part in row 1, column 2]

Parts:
IC1, IC13: RAMSOCK32TO512KSOP; SOP32
JP7: JP4E; JP4
QG1: 50MHz; SG51
R5, R12: 1k; 0207/2V
R9, R10, R11: 10k; 0207/2V
U$1: W65C816SPLCC; PLCC44
U$2: XC95288XLTQ144; TQFP144
U$4: SPIFLASH; DIL08
U$7: XILINXPROG; FLAT10BOX

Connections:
50M: QG1.8 (OUT), U$2.30 (GCK0)
/FRAMSEL: IC1.22 (/CS), IC1.24 (/OE), U$2.2 (GTS2)
/IRQ: R9.2, U$1.5 (IRQB); also elsewhere on the board
/NMI: JP7.4, R11.2, U$1.7 (NMIB)
/RAMCS: IC13.22 (/CS), IC13.24 (/OE), U$2.126 (FB10MC12)
/RAMWE: IC13.29 (/WE), U$2.139 (FB6MC8)
/RES: JP7.1, U$1.44 (RESB), U$2.143 (GSR); also elsewhere on the board
/SEL1: U$2.69 (FB11MC14); also elsewhere on the board
/SEL2: U$2.68 (FB11MC12); also elsewhere on the board
/SEL4: U$2.66 (FB11MC11); also elsewhere on the board
A0: IC1.12 (A0), U$1.10 (A0), U$2.104 (FB14MC10); also elsewhere on the board
A1: IC1.11 (A1), U$1.11 (A1), U$2.103 (FB14MC8); also elsewhere on the board
A2: IC1.10 (A2), U$1.13 (A2), U$2.102 (FB14MC6); also elsewhere on the board
A3: IC1.9 (A3), U$1.14 (A3), U$2.101 (FB14MC5); also elsewhere on the board
A4: IC1.8 (A4), U$1.15 (A4), U$2.100 (FB14MC3)
A5: IC1.7 (A5), U$1.16 (A5), U$2.98 (FB16MC12)
A6: IC1.6 (A6), U$1.17 (A6), U$2.97 (FB16MC11)
A7: IC1.5 (A7), U$1.18 (A7), U$2.96 (FB16MC10)
A8: IC1.27 (A8), U$1.19 (A8), U$2.95 (FB16MC8)
A9: IC1.26 (A9), U$1.20 (A9), U$2.94 (FB16MC6)
A10: IC1.23 (A10), U$1.21 (A10), U$2.93 (FB16MC5)
A11: IC1.25 (A11), U$1.22 (A11), U$2.92 (FB16MC3)
A12: IC1.4 (A12), U$1.25 (A12), U$2.91 (FB16MC2)
A13: IC1.28 (A13), U$1.26 (A13), U$2.87 (FB15MC15)
A14: IC1.3 (A14), U$1.27 (A14), U$2.88 (FB15MC17)
A15: U$1.28 (A15), U$2.85 (FB15MC12)
ABORTB: JP7.2, R10.2, U$1.4 (ABORTB)
D0: IC1.13 (O0), U$1.36 (D0/BA0), U$2.86 (FB15MC14); also elsewhere on the board
D1: IC1.14 (O1), U$1.35 (D1/BA1), U$2.83 (FB15MC11); also elsewhere on the board
D2: IC1.15 (O2), U$1.34 (D2/BA2), U$2.82 (FB15MC10); also elsewhere on the board
D3: IC1.17 (O3), U$1.33 (D3/BA3), U$2.81 (FB15MC8); also elsewhere on the board
D4: IC1.18 (O4), U$1.32 (D4/BA4), U$2.80 (FB15MC3); also elsewhere on the board
D5: IC1.19 (O5), U$1.31 (D5/BA5), U$2.79 (FB15MC2); also elsewhere on the board
D6: IC1.20 (O6), U$1.30 (D6/BA6), U$2.78 (FB13MC17); also elsewhere on the board
D7: IC1.21 (O7), U$1.29 (D7/BA7), U$2.77 (FB13MC15); also elsewhere on the board
DCLK: U$2.45 (FB7MC3); also elsewhere on the board
DENA: U$2.41 (FB5MC14); also elsewhere on the board
E: U$1.39 (E), U$2.142 (FB6MC14)
FA15: IC1.31 (A15), U$2.71 (FB13MC2)
FA16: IC1.2 (A16), U$2.105 (FB14MC11)
FA17: IC1.30 (A17/CE2/VCC), U$2.106 (FB14MC14)
FA18: IC1.1 (A18), U$2.107 (FB14MC15)
GND: IC1.16 (GND), IC13.16 (GND), JP7.3, QG1.7 (VSS), U$1.1, U$1.23 (VSS), U$1.24 (GND), U$2.18 (GND), U$2.29 (GND), U$2.36 (GND), U$2.47 (GND), U$2.62 (GND), U$2.72 (GND), U$2.89 (GND), U$2.90 (GND), U$2.99 (GND), U$2.108 (GND), U$2.114 (GND), U$2.123 (GND), U$2.144 (GND), U$4.4 (GND), U$7.2 (GND), U$7.10; also elsewhere on the board
GRAPHIC: U$2.70 (FB11MC17); also elsewhere on the board
HSYNC: U$2.48 (FB7MC12); also elsewhere on the board
M/X: U$1.42 (M/X), U$2.24 (FB1MC12)
MLB: U$1.6 (MLB), U$2.21 (FB1MC6)
PET_VSYNC: U$2.43 (FB5MC15); also elsewhere on the board
PHI2: R12.2, U$1.41 (PH2-IN), U$2.57 (FB9MC12)
PHI2_IO: R5.1, U$2.38 (GCK2); also elsewhere on the board
R/-W: IC1.29 (/WE), U$1.38 (R/WB), U$2.20 (FB1MC5); also elsewhere on the board
RAMA0: IC13.12 (A0), U$2.119 (FB10MC5)
RAMA1: IC13.11 (A1), U$2.120 (FB10MC6)
RAMA2: IC13.10 (A2), U$2.121 (FB10MC8)
RAMA3: IC13.9 (A3), U$2.125 (FB10MC11)
RAMA4: IC13.8 (A4), U$2.130 (FB8MC2)
RAMA5: IC13.7 (A5), U$2.132 (FB8MC5)
RAMA6: IC13.6 (A6), U$2.134 (FB8MC10)
RAMA7: IC13.5 (A7), U$2.136 (FB6MC3)
RAMA8: IC13.27 (A8), U$2.135 (FB6MC2)
RAMA9: IC13.26 (A9), U$2.133 (FB8MC8)
RAMA10: IC13.23 (A10), U$2.124 (FB10MC10)
RAMA11: IC13.25 (A11), U$2.131 (FB8MC3)
RAMA12: IC13.4 (A12), U$2.138 (FB6MC6)
RAMA13: IC13.28 (A13), U$2.137 (FB6MC5)
RAMA14: IC13.3 (A14), U$2.7 (FB4MC14)
RAMA15: IC13.31 (A15), U$2.10 (FB2MC3)
RAMA16: IC13.2 (A16), U$2.9 (FB2MC2)
RAMA17: IC13.30 (A17/CE2/VCC), U$2.4 (FB4MC6)
RAMA18: IC13.1 (A18), U$2.11 (FB2MC5)
RAMD0: IC13.13 (O0), U$2.116 (FB12MC12)
RAMD1: IC13.14 (O1), U$2.113 (FB12MC8)
RAMD2: IC13.15 (O2), U$2.111 (FB12MC3)
RAMD3: IC13.17 (O3), U$2.110 (FB12MC2)
RAMD4: IC13.18 (O4), U$2.112 (FB12MC5)
RAMD5: IC13.19 (O5), U$2.115 (FB12MC10)
RAMD6: IC13.20 (O6), U$2.58 (FB9MC14)
RAMD7: IC13.21 (O7), U$2.59 (FB9MC17)
RDY: U$1.3 (RDY)
SPI_CLK: U$2.50 (FB9MC2), U$4.6 (SCK); also elsewhere on the board
SPI_IN1: U$2.129 (FB10MC17), U$4.2 (SO); also elsewhere on the board
SPI_IN3: U$2.118 (FB10MC3); also elsewhere on the board
SPI_NFLASH: U$2.52 (FB9MC5), U$4.1 (/CS)
SPI_NSEL2: U$2.34 (FB5MC2); also elsewhere on the board
SPI_NSEL3: U$2.39 (FB5MC10); also elsewhere on the board
SPI_NSEL4: U$2.40 (FB5MC12); also elsewhere on the board
SPI_NSEL5: U$2.60 (FB11MC3); also elsewhere on the board
SPI_OUT: U$2.54 (FB9MC8), U$4.5 (SI); also elsewhere on the board
TCK: U$2.67 (TCK), U$7.1 (TCK)
TDI: U$2.63 (TDI), U$7.9 (TDI)
TDO: U$2.122 (TDO), U$7.3 (TDO)
TMS: U$2.65 (TMS), U$7.5 (TMS)
V33: R9.1, U$2.1 (VIO), U$2.8 (VCC), U$2.37 (VIO), U$2.42 (VCC), U$2.55 (VIO), U$2.73 (VIO), U$2.84 (VCC), U$2.109 (VIO), U$2.127 (VIO), U$2.141 (VCC), U$4.7 (/HOLD), U$4.8 (VCC), U$7.4 (VCC); also elsewhere on the board
VCC: IC1.32 (VCC), IC13.32 (VCC), QG1.14 (VDD), R5.2, R10.1, R11.1, R12.1, U$1.9 (VCC), U$1.37 (VDD), U$1.40 (BE); also elsewhere on the board
VDA: U$1.43 (VDA), U$2.75 (FB13MC11)
VIDEO: U$2.46 (FB7MC5); also elsewhere on the board
VPA: U$1.8 (VPA), U$2.74 (FB13MC8)
VPB: U$1.2 (VPB), U$2.22 (FB1MC8)
VSYNC: U$2.49 (FB7MC15); also elsewhere on the board

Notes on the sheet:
MICROPET-V2.0C-20210515
MICROPET-V2.1A
(C) A. Fachat
SHEET 2/5
V2.0C: pull up on /IRQ to 3.3V, to protect SPI devices from 5V
V2.0B: - do not use '245 level converter but pullup R for PHI2 and PHI2_IO - Add missing SPI_NSEL5

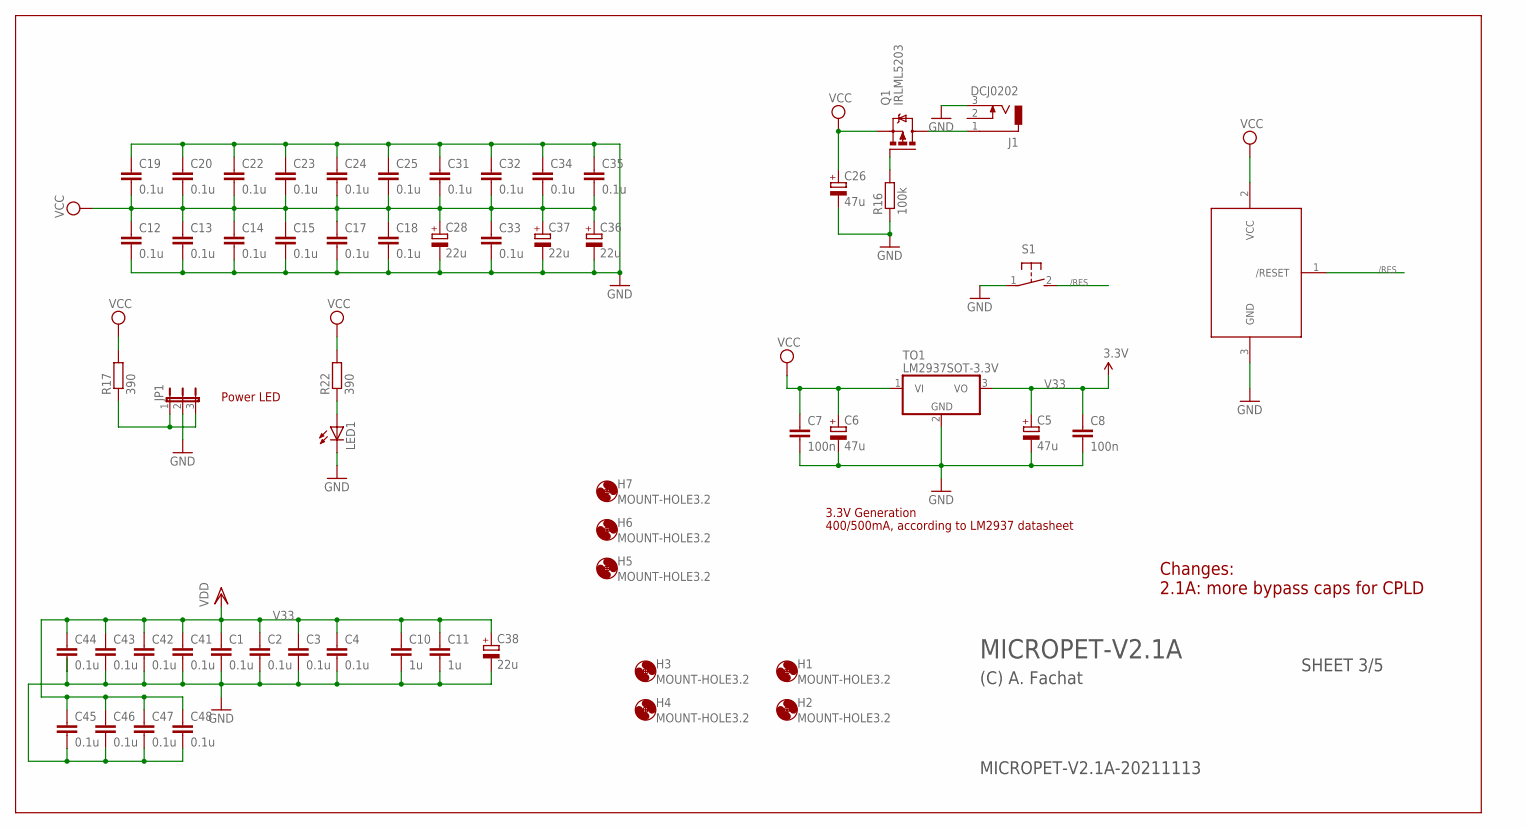
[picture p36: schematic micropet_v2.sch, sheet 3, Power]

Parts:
C1, C2, C3, C4, C12, C13, C14, C15, C17, C18, C19, C20, C22, C23, C24, C25, C31, C32, C33, C34, C35, C41, C42, C43, C44, C45, C46, C47, C48: 0.1u; C0603
C5: 47u; E5-8,5
C6: 47u; E5-6
C7, C8: 100n; C0603
C10, C11: 1u; C0603
C26: 47u; E2,5-6
C28, C36, C37, C38: 22u; E2,5-6
H1, H2, H3, H4, H5, H6, H7: MOUNT-HOLE3.2; 3,2
J1: DCJ0202
JP1: JP2E; JP2
LED1: LED3MM
Q1: IRLML5203; MICRO3
R16: 100k; 0207/2V
R17, R22: 390; 0207/2V
S1: 31-XX; B3F-31XX
TO1: LM2937SOT-3.3V; SOT223
U$3: DS1813; TO92

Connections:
/RES: S1.2 (S), U$3.1 (/RESET); also elsewhere on the board
GND: C1.2, C2.2, C3.2, C4.2, C5.-, C6.-, C7.2, C8.2, C10.2, C11.2, C12.2, C13.2, C14.2, C15.2, C17.2, C18.2, C19.1, C20.1, C22.1, C23.1, C24.1, C25.1, C26.-, C28.-, C31.1, C32.1, C33.2, C34.1, C35.1, C36.-, C37.-, C38.-, C41.2, C42.2, C43.2, C44.2, C45.2, C46.2, C47.2, C48.2, J1.3, JP1.2, LED1.K (C), R16.1, S1.1, TO1.2 (GND), U$3.3 (GND); also elsewhere on the board
unnamed: J1.1, Q1.3 (D)
unnamed: Q1.1 (G), R16.2
unnamed: JP1.1, JP1.3, R17.1
unnamed: LED1.A, R22.1
V33: C1.1, C2.1, C3.1, C4.1, C5.+, C8.1, C10.1, C11.1, C38.+, C41.1, C42.1, C43.1, C44.1, C45.1, C46.1, C47.1, C48.1, TO1.3 (VO); also elsewhere on the board
VCC: C6.+, C7.1, C12.1, C13.1, C14.1, C15.1, C17.1, C18.1, C19.2, C20.2, C22.2, C23.2, C24.2, C25.2, C26.+, C28.+, C31.2, C32.2, C33.1, C34.2, C35.2, C36.+, C37.+, Q1.2 (S), R17.2, R22.2, TO1.1 (VI), U$3.2 (VCC); also elsewhere on the board

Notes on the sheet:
MICROPET-V2.1A-20211113
MICROPET-V2.1A
(C) A. Fachat
SHEET 3/5
3.3V Generation
400/500mA, according to LM2937 datasheet
Power LED
Changes: 2.1A: more bypass caps for CPLD

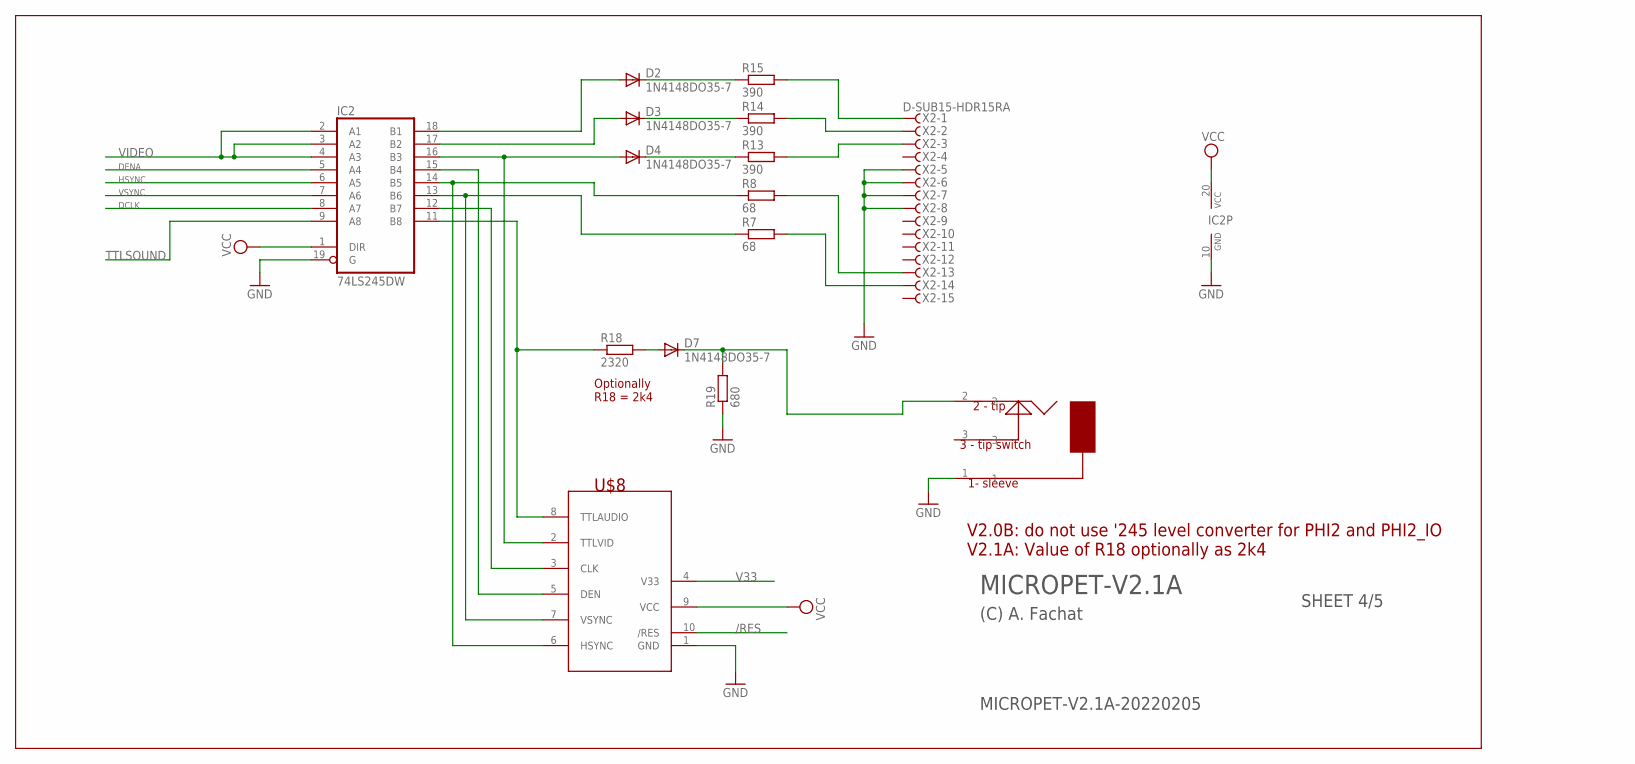
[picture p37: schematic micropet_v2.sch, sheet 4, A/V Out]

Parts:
D2, D3, D4, D7: 1N4148DO35-7; DO35-7
IC2: 74LS245DW; SO20W
R7, R8: 68; 0204V
R13, R14, R15: 390; 0204V
R18: 2320; 0204V
R19: 680; 0204V
U$8: MONOVIDAUDIO; FLAT10RIB
U$10: MONOAUDIOB; CUI_MJ-3502-B
X2: D-SUB15-HDR15RA; HDR15RA

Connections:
/RES: U$8.10 (/RES); also elsewhere on the board
DCLK: IC2.8 (A7); also elsewhere on the board
DENA: IC2.5 (A4); also elsewhere on the board
GND: IC2.10 (GND), IC2.19 (G), R19.1, U$8.1 (GND), U$10.1, X2.5, X2.6, X2.7, X2.8; also elsewhere on the board
HSYNC: IC2.6 (A5); also elsewhere on the board
unnamed: IC2.11 (B8), R18.1, U$8.8 (TTLAUDIO)
unnamed: D2.A, IC2.18 (B1)
unnamed: IC2.13 (B6), R7.1, U$8.7 (VSYNC)
unnamed: IC2.12 (B7), U$8.3 (CLK)
unnamed: R15.2, X2.1
unnamed: R14.2, X2.2
unnamed: R13.2, X2.3
unnamed: R8.2, X2.13
unnamed: R7.2, X2.14
unnamed: IC2.14 (B5), R8.1, U$8.6 (HSYNC)
unnamed: IC2.15 (B4), U$8.5 (DEN)
unnamed: D4.A, IC2.16 (B3), U$8.2 (TTLVID)
unnamed: D2.C, R15.1
unnamed: D3.C, R14.1
unnamed: D4.C, R13.1
unnamed: D7.A, R18.2
unnamed: D7.C, R19.2, U$10.2
unnamed: D3.A, IC2.17 (B2)
TTLSOUND: IC2.9 (A8); also elsewhere on the board
V33: U$8.4 (V33); also elsewhere on the board
VCC: IC2.1 (DIR), IC2.20 (VCC), U$8.9 (VCC); also elsewhere on the board
VIDEO: IC2.2 (A1), IC2.3 (A2), IC2.4 (A3); also elsewhere on the board
VSYNC: IC2.7 (A6); also elsewhere on the board

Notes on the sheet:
MICROPET-V2.1A-20220205
MICROPET-V2.1A
(C) A. Fachat
SHEET 4/5
V2.0B: do not use '245 level converter for PHI2 and PHI2_IO V2.1A: Value of R18 optionally as 2k4
Optionally R18 = 2k4

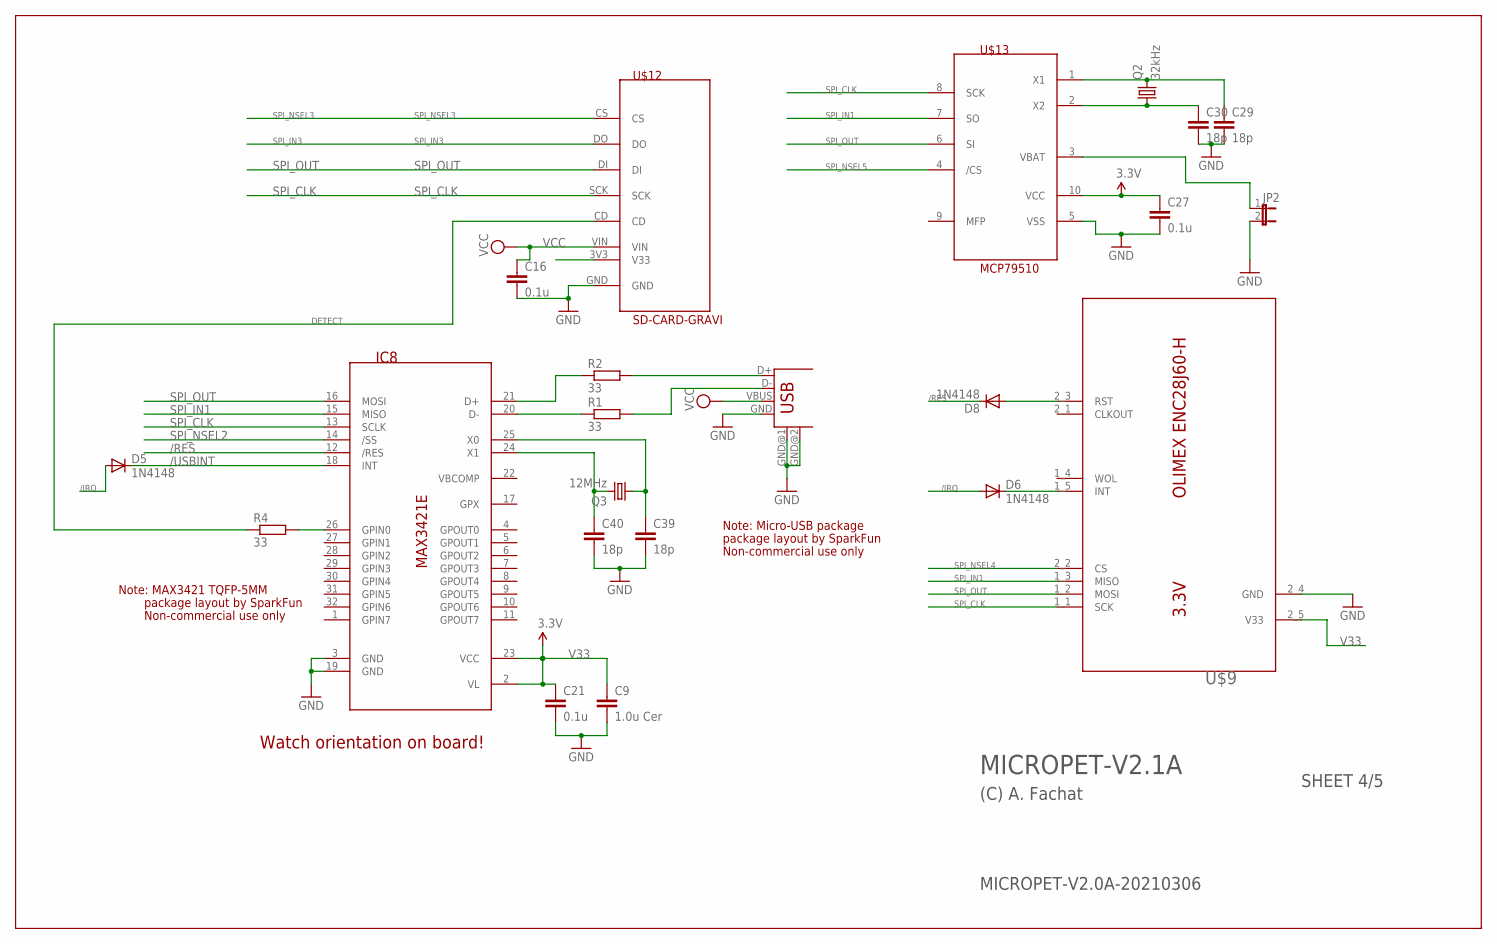
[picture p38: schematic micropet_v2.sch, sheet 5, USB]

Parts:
C9: 1.0u Cer; C0603
C16, C21, C27: 0.1u; C0603
C29, C30, C39, C40: 18p; C0603
D5, D6, D8: 1N4148; D-5
IC8: MAX3421E; TQFP32-5MM
JP2: JP1E; JP1
Q2: 32kHz; TC26H
Q3: 12MHz; HC49/S
R1, R2, R4: 33; 0204/7
U$9: ETHOLIENC
U$12: SD-CARD-GRAVI; GRAVITECH-SDCARD
U$13: MCP79510; MSOP10
USB1: USB-A-H

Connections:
12MHZ: C40.1, IC8.24 (X1), Q3.2
/IRQ: D5.A, D6.A; also elsewhere on the board
/RES: D8.C, IC8.12 (/RES); also elsewhere on the board
/USBINT: D5.C, IC8.18 (INT)
DETECT: R4.1, U$12.CD
FOO: U$12.3V3 (V33)
GND: C9.2, C16.2, C21.2, C27.2, C29.2, C30.2, C39.2, C40.2, IC8.3 (GND), IC8.19 (GND), JP2.2, U$9.2_4 (GND), U$12.GND, U$13.5 (VSS), USB1.GND, USB1.GND@1 (GND), USB1.GND@2 (GND); also elsewhere on the board
unnamed: IC8.20 (D-), R1.1
unnamed: IC8.21 (D+), R2.1
unnamed: JP2.1, U$13.3 (VBAT)
unnamed: C29.1, Q2.2, U$13.1 (X1)
unnamed: D6.C, U$9.1_5 (INT)
unnamed: R2.2, USB1.D+
unnamed: R1.2, USB1.D-
unnamed: IC8.26 (GPIN0), R4.2
unnamed: C30.1, Q2.1, U$13.2 (X2)
unnamed: D8.A, U$9.2_3 (RST)
unnamed: C39.1, IC8.25 (X0), Q3.1
SPI_CLK: IC8.13 (SCLK), U$9.1_1 (SCK), U$12.SCK, U$13.8 (SCK); also elsewhere on the board
SPI_IN1: IC8.15 (MISO), U$9.1_3 (MISO), U$13.7 (SO); also elsewhere on the board
SPI_IN3: U$12.DO; also elsewhere on the board
SPI_NSEL2: IC8.14 (/SS); also elsewhere on the board
SPI_NSEL3: U$12.CS; also elsewhere on the board
SPI_NSEL4: U$9.2_2 (CS); also elsewhere on the board
SPI_NSEL5: U$13.4 (/CS); also elsewhere on the board
SPI_OUT: IC8.16 (MOSI), U$9.1_2 (MOSI), U$12.DI, U$13.6 (SI); also elsewhere on the board
V33: C9.1, C21.1, C27.1, IC8.2 (VL), IC8.23 (VCC), U$9.2_5 (V33), U$13.10 (VCC); also elsewhere on the board
VCC: C16.1, U$12.VIN, USB1.VBUS; also elsewhere on the board

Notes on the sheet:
Watch orientation on board!
Note: MAX3421 TQFP-5MM
Non-commercial use only
package layout by SparkFun
MICROPET-V2.0A-20210306
MICROPET-V2.1A
(C) A. Fachat
SHEET 4/5
Note: Micro-USB package

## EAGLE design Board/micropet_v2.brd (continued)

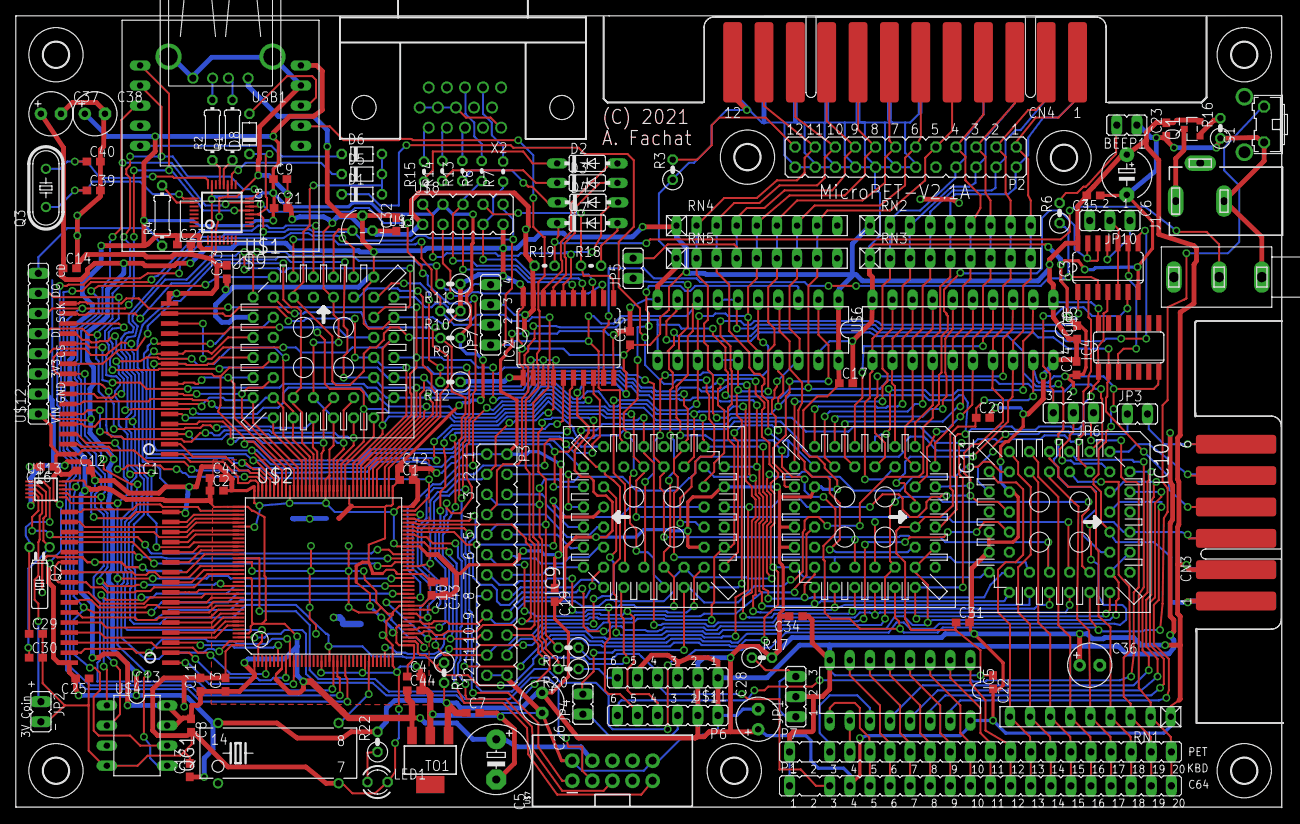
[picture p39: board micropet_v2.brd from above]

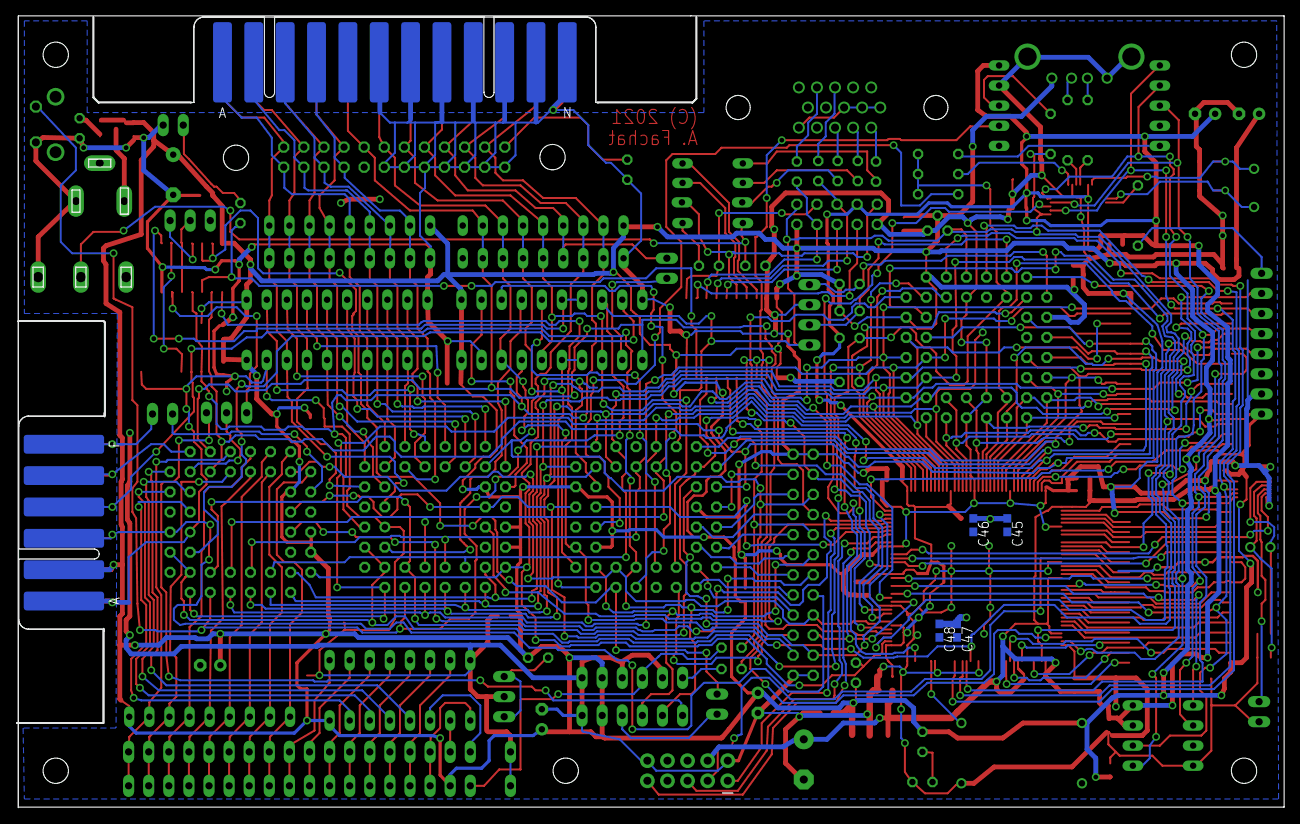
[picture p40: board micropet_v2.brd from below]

Board: 2 copper layers, 160.0 x 100.1 mm, 139 parts (4 on the bottom side), 217 nets.

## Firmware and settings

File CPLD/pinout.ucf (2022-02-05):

# NET VD<0>	LOC=P142 | IOSTANDARD=LVCMOS33 |PULLUP;
# NET VD<0>	LOC=P142 | IOSTANDARD=LVCMOS33 | DRIVE=16;

NET VD<0>	LOC=P116;
NET VD<1>	LOC=P113;
NET VD<2>	LOC=P111;
NET VD<3>	LOC=P110;
NET VD<4>	LOC=P112;
NET VD<5>	LOC=P115;
NET VD<6>	LOC=P58;
NET VD<7>	LOC=P59;

NET VA<0>	LOC=P119;
NET VA<0>	LOWPWR;
NET VA<1>	LOC=P120;
NET VA<1>	LOWPWR;
NET VA<2>	LOC=P121;
NET VA<2>	LOWPWR;
NET VA<3>	LOC=P125;
NET VA<3>	LOWPWR;
NET VA<4>	LOC=P130;	#P126;
NET VA<4>	LOWPWR;
NET VA<5>	LOC=P131;	# actually P132, P131 is VA11
NET VA<5>	LOWPWR;
NET VA<6>	LOC=P133;	# actually P134, P133 is VA9
NET VA<6>	LOWPWR;
NET VA<7>	LOC=P136;
NET VA<7>	LOWPWR;
NET VA<8>	LOC=P135;
NET VA<8>	LOWPWR;
NET VA<9>	LOC=P132;	# actually P133, P132 is VA5
NET VA<9>	LOWPWR;
NET VA<10>	LOC=P124;
NET VA<10>	LOWPWR;
NET VA<11>	LOC=P134;	# actually P131, P134 is VA6
NET VA<11>	LOWPWR;
NET VA<12>	LOC=P138;
NET VA<12>	LOWPWR;
NET VA<13>	LOC=P137;
NET VA<13>	LOWPWR;
NET VA<14>	LOC=P7;
NET VA<14>	LOWPWR;
NET VA<15>	LOC=P10;
NET VA<15>	LOWPWR;
NET VA<16>	LOC=P9;
NET VA<16>	LOWPWR;
NET VA<17>	LOC=P4;
NET VA<17>	LOWPWR;
NET VA<18>	LOC=P11;
NET VA<18>	LOWPWR;

NET FA<15>	LOC=P71;
NET FA<16>	LOC=P105;
NET FA<17>	LOC=P106;
NET FA<18>	LOC=P107;

NET D<0>	LOC=P86;
NET D<1>	LOC=P83;
NET D<2>	LOC=P82;
NET D<3>	LOC=P81;
NET D<4>	LOC=P80;
NET D<5>	LOC=P79;
NET D<6>	LOC=P78;
NET D<7>	LOC=P77;

NET A<0>	LOC=P104;
NET A<1>	LOC=P103;
NET A<2>	LOC=P102;
NET A<3>	LOC=P101;
NET A<4>	LOC=P100;
NET A<5>	LOC=P98;
NET A<6>	LOC=P97;
NET A<7>	LOC=P96;
NET A<8>	LOC=P95;
NET A<9>	LOC=P94;
NET A<10>	LOC=P93;
NET A<11>	LOC=P92;
NET A<12>	LOC=P91;
NET A<13>	LOC=P87;
NET A<14>	LOC=P88;
NET A<15>	LOC=P85;

NET VPA		LOC=P74;
NET VDA		LOC=P75;
	
NET NSEL1	LOC=P69;
NET NSEL2	LOC=P68;
NET NSEL4	LOC=P66;

NET NVRAMSEL	LOC=P126;
NET NFRAMSEL	LOC=P2;
NET RAMRWB	LOC=P139;

NET GRAPHIC	LOC=P70;

NET HSYNC	LOC=P48;
NET VSYNC	LOC=P49;
NET PXL 	LOC=P46; 
NET DCLK	LOC=P45;
NET DENA	LOC=P41;
NET PET_VSYNC	LOC=P43;

NET Q50M	LOC=P30;
NET Q50M	BUFG=CLK;

NET RWB		LOC=P20;
NET NRES	LOC=P143;
NET NRES	BUFG=SR;

NET PHI2_IO	LOC=P38;
NET PHI2_IO	BUFG=CLK;

NET MLB		LOC=P21;
NET VPB		LOC=P22;
NET E			LOC=P142;
NET MX			LOC=P24;

NET SPI_OUT		LOC=P54;
NET SPI_CLK		LOC=P50;

NET SPI_IN1		LOC=P129;
NET SPI_IN3		LOC=P118;

NET NFLASH		LOC=P52;
NET SPI_NSEL2		LOC=P34;
NET SPI_NSEL3		LOC=P39;
NET SPI_NSEL4		LOC=P40;

NET SPI_NSEL5		LOC=P60;

#NET MEMCLK		BUFG=CLK;
#NET MEMCLK		NOREDUCE;

#NET PHI2		BUFG=CLK;
NET PHI2		LOC=P57;

#NET UNUSED<0>		LOC=P5;
#NET UNUSED<0>		LOWPWR;
#NET UNUSED<0>		PULLDOWN;		# unsupported for XC9500..
#NET UNUSED<1>		LOC=P6;
#NET UNUSED<1>		LOWPWR;
#NET UNUSED<2>		LOC=P3;
#NET UNUSED<2>		LOWPWR;
#NET UNUSED<3>		LOC=P23;
#NET UNUSED<3>		LOWPWR;
#NET UNUSED<4>		LOC=P25;
#NET UNUSED<4>		LOWPWR;
#NET UNUSED<5>		LOC=P26;
#NET UNUSED<5>		LOWPWR;
#NET UNUSED<6>		LOC=P27;
#NET UNUSED<6>		LOWPWR;
#NET UNUSED<7>		LOC=P12;
#NET UNUSED<7>		LOWPWR;
#NET UNUSED<8>		LOC=P13;
#NET UNUSED<8>		LOWPWR;
#NET UNUSED<9>		LOC=P14;
#NET UNUSED<9>		LOWPWR;
#NET UNUSED<10>		LOC=P15;
#NET UNUSED<10>		LOWPWR;
#NET UNUSED<11>		LOC=P16;
#NET UNUSED<11>		LOWPWR;
#NET UNUSED<12>		LOC=P17;
#NET UNUSED<12>		LOWPWR;
#NET UNUSED<13>		LOC=P19;
#NET UNUSED<13>		LOWPWR;
#NET UNUSED<14>		LOC=P28;
#NET UNUSED<14>		LOWPWR;
#NET UNUSED<15>		LOC=P31;
#NET UNUSED<15>		LOWPWR;
#NET UNUSED<16>		LOC=P33;
#NET UNUSED<16>		LOWPWR;
#NET UNUSED<17>		LOC=P44;
#NET UNUSED<17>		LOWPWR;
#NET UNUSED<18>		LOC=P140;
#NET UNUSED<18>		LOWPWR;
#NET UNUSED<19>		LOC=P51;
#NET UNUSED<19>		LOWPWR;
#NET UNUSED<20>		LOC=P53;
#NET UNUSED<20>		LOWPWR;
#NET UNUSED<21>		LOC=P56;
#NET UNUSED<21>		LOWPWR;
#NET UNUSED<22>		LOC=P117;
#NET UNUSED<22>		LOWPWR;
#NET UNUSED<23>		LOC=P128;
#NET UNUSED<23>		LOWPWR;
#NET UNUSED<24>		LOC=P61;
#NET UNUSED<24>		LOWPWR;
#NET test		LOC=P64;
#NET test		LOWPWR;
#NET dbg_out		LOC=P76;
#NET dbg_out		LOWPWR;

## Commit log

2020-12-24 Initial release for the MicroPET
    [micropet_v1.brd, micropet_v1.sch]
2020-12-28 Move to 50MHz main clock oscillator
    [pinout.ucf]
2021-01-04 implement SPI interface at
2021-01-04 Add SPI documentation
2021-01-04 Fixed SPI receive timing; ATTN: do not set jumpers on the mode inputs, they are outputs in this version
    [pinout.ucf]
2021-01-05 invert select line for Flash ROM
    [pinout.ucf]
2021-01-05 inital SPI boot - needs simple Mapper due to device resource limits
2021-01-06 Boots from SPI Flash without parallel ROM
2021-01-06 Remove parallel ROM support, 3 SPI channels, add. video output, esp pet_vsync
2021-01-06 Board Rev 1.0F
    [micropet_v1.brd, micropet_v1.sch]
2021-01-06 remove ROM from pinout, shuffle pins, add SPI channels
2021-01-10 add fourth SPI channel
2021-01-10 Board Rev 1.1A
    [micropet_v1.brd, micropet_v1.sch]
2021-01-17 Fixup Composite video timing (now rock solid on my tv, and works with capturing device)
2021-01-23 Board version 1.1B
    [micropet_v1.brd, micropet_v1.sch]
2021-02-07 optimize, add 5th SPI channel
2021-02-13 introduce CPOL and CPHA in the SPI module
2021-02-13 introduce CPOL and CPHA in the SPI module
    Conflicts:
    CPLD/SPI.vhd
    CPLD/work/Top.jed
2021-02-14 update SPI boot ROM build and instructions
2021-05-02 fix pinout for board 2.0A
    [pinout.ucf]
2021-05-09 MicroPET R2.0B board
    [micropet_v1.brd, micropet_v1.sch, micropet_v2.brd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]
2021-05-10 updated spi Flash image
2021-06-03 use half the native SPI speed on the RTCC chip
2021-07-23 Updated R2 main readme, added keyboard/case files
    [C64 keyboard support.stl, Commodore PET caps for N keyboard fine slices(1).stl, Commodore PET caps for N keyboard fine slices(2).stl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]
2021-07-24 fix links, typos, update case
2021-07-25 update board to 2.0C
    [micropet_v2.brd, micropet_v2.sch]
2021-07-28 update README, init control registers at warm boot
    [C64c keyboard support plate.stl]
2021-08-19 fix SPI description
2022-02-05 Micropet V2.1A
    [micropet_v2.brd, micropet_v2.sch]
2022-02-05 update case support links and description
    [Lower petskey keyboard support.stl, Lower sjg keyboard support.stl, petskey full support plate.stl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]
2022-02-06 switch Ethernet to low power on boot
2022-02-08 small optimization on SPI interface
2022-02-08 add link to SPI doc in README
2022-02-19 switch SPI clock for RTC chip from 6MHz to 3MHz (spec is below 5MHz)

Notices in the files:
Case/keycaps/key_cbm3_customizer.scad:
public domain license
